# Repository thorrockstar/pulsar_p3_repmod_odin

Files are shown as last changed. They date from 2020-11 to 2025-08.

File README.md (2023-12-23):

Open Source Pulsar P3 Replacement Module 'Odin' & 'Loki'
========================================================

This project bundles my source code, binary, schematics and PCB layout files for my own Open Source Pulsar P3 LED watch replacement modules. I do **not** sell those modules or any component and I do **not** do any repairs. This project is purely for the enthusiast, that want to fix a Pulsar LED watch himself or herself, that is far beyond repair otherwise. This project is **not** meant to be used commercially.

The PCB layout is made in a way, allowing it to be opened and edited with the free Eagle version. I prefer the older Eagle 6.6 release, that still was made by CADSoft.

The free trial version of the CAD-Soft Eagle software can be found on CAD-Softs's own FTP server:
http://eagle.autodesk.com/eagle/software-versions/10

P3 Module Types
===============

This project contains two different boards. The **Odin Mark II** board, that can be used, if the **original Litronix** dotty LED display could be rescued. The **Loki** board can be used if the original display is broken and shall be replaced with four USSR made **AL304G replacement** single digit displays with common anodes. See the comments in the schematics.

**Note:** Some of the photos show **older** variants of the boards. So don't get confused. The current Odin Mark II features **4 extra transistors** for driving the common cathodes.

**Important Note:** As the new PCB's have traces and vias/pads on the back side, make sure you put some black isolation tape on top of the plastic carrier *before* placing the new PCB onto it. Otherwise the battery connection wires may short your PCB!

P4 Module Variant
=================

There is a sub-folder called 'p4mod', that contains a module called **Sif**. This one can be used for P4 Executive watches. It has the micro controller on the back side. So, double check the orientation of the chip, when soldering, as the PCB is shown from the top layer in the pictures and you need to turn the PCB over when soldering. Be aware, that you will need to **modify the plastic carrier**. You will be in need to make the open space behind the PCB wider, to be able to place the PCB flush on the P4 plastic carrier. I usually do that by cutting the edges on the top and bottom of the inner opening in order to create a 45 degree angle there.

License Agreement
=================

The software, source code, schematics, drawings and resources are provided to you by the Licensor under the License, as defined below, subject to the following condition.

Without limiting other conditions in the License, the grant of rights under the License will not include, and the License does not grant to you, the right to sell the software, source code, schematics, drawings or resources.

The Licensor does not grant the right to produce watch modules on the base of this work and then sell them as a product for profit.

These schematics, layout and source code files are free software; you can redistribute them and/or modify them under the terms of the GNU General Public License as published by the Free Software Foundation in version 2 of the License.

These source code, schematics, drawings and layout files are distributed in the hope that they will be useful, but WITHOUT ANY WARRANTY; without even the implied warranty of MERCHANTABILITY or FITNESS FOR A PARTICULAR PURPOSE. See the GNU General Public License for more details.

Hardware & Software
===================

This project features a MicroChip PIC18F24J11 MCU. The software can be compiled using Microchip's MPLAB IDE and the XC8 compiler. You can get those free for private use. To flash the controller I used a PICKIT™3 unit. You still get those units second hand or NOS but you can also use a more recent one.

**Module 'Odin' featuring the original display and light sensor.**

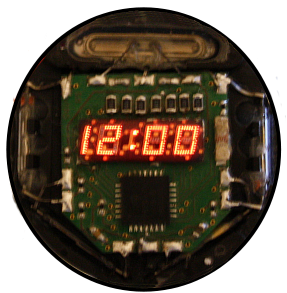
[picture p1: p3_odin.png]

(Older Odin 1)
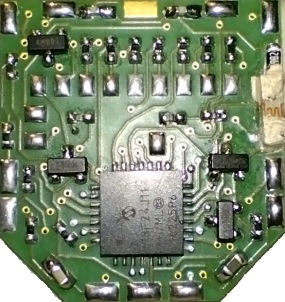
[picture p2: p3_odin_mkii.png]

(Newer Odin Mark II)

In the main header file, select the right type of watch module. You find also ready compiled binaries for the 'Odin' and 'Loki' module.

**Module 'Loki' featuring four replacement single digit displays and no light sensor.**

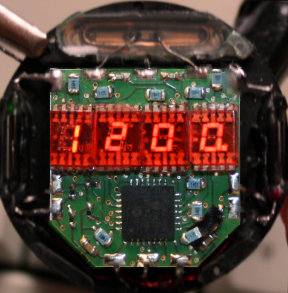
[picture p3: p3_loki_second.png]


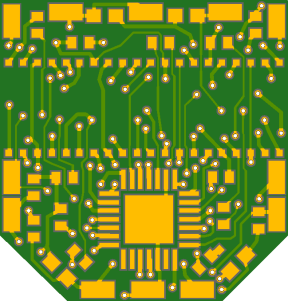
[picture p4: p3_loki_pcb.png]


Important
==========
We do **not** do any repairs or deliver any components. This is a pure Open Source project, were I share my files, that I used to create a replacement module for one of my old watches, that was corroded beyond repair. This project shall not be used commercially.

Contributing
============
To contribute to this project you should submit your proposals to the maintainer via GitHub.

Maintainer
==========
Dipl.-Ing.(FH) Roy Schneider

Useful Information
==================

More information about old Pulsar LED watches, can be found here:

Pulsar LED Watch Forum:
http://www.oldpulsars.com/

PCB
===

If you order your PCB at some manufacturer, go for the 1mm material thickness, not more. You need a thin PCB to ensure, you have enough clearance to the watch case glass, when the display has been installed. A traces thickness of 35 µm is good enough. Order the PCB with a solder stop mask. That simplifies soldering a lot. You usually do not need a silk screen. Order ENIG (Electroless Nickel Gold) surface (traces) for best solder results.

Energy Consumption
==================

The watch currently draws about 7 µA (0.007 mA) of current, if the display is not lit up. Assuming your silver oxide batteries would have 160mAh, the battery life time would be a year, depending how often you use the display. You may use Alkaline batteries but I suggest to use Silver Oxide batteries having 1.55V and a larger capacity.

Setting the Time & Date of the Replacement Module
=================================================

To forward the hours, place the magnet in the HOURS recess. To forward the minutes, place the magnet in the MINUTES recess. Keep in mind that the watch will stop counting the time, if you have forwarded the minutes, until you will press the first time the readout TIME button. This gives you an easy way to set the watch second-accurate, by setting the watch one minute into the future and then wait until the reference clock wraps to that very minute. If you press the TIME button in that moment, the watch will continue counting the time, having set the seconds to zero. To forward the month hold the DATE button pressed and place the magnet in the HOUR recess. To forward the day hold the DATE and TIME buttons pressed at the same time and place the magnet in the HOUR recess. This replacement module adds the weekday, the year and the light sensor read-out to the watch. Refer to the next chapter for setting them.

Settings the Extra Features of the Firmware not included in the original P3
===========================================================================

The firmware for this replacement module adds two additional functions to the watch. It adds the weekday and the year. To set the year hold the DATE and TIME button pressed and forward the year by putting the magnet into the MIN recess. To set the weekday hold only the DATE button pressed and forward the weekday by putting the magnet into the MIN recess. If you face the issue that you set the year instead of the weekday, then the magnet is very strong and engages not only the MIN but also the TIME reed contact. Try turning the magnet around in that case.

Optional Alarm Feature of the 'Loki Module'
============================================

This feature is only available for the 'Loki' modules, using the USSR made replacement displays. You can use the output RC2 of the micro controller in order to drive a disc piezo buzzer with a 820Ohm...1kOhm resistor in series. To use that feature turn the ALARM option on in the main.h header file and rebuild the binary.

**Note:**

Don't expect the alarm to be loud... it will not be loud enough to wake you up, simply because it is silenced by the massive metal case of the watch. :-)

**Set Alarm**

In order to set the alarm, press the TIME (hold) and then the DATE (hold) button in this exact order ands keep them pressed together. Now you can place the magnet in the HOUR or MIN recess to set the alarm.

**Toggle Alarm (on/off)**

To turn the alarm on or off press the TIME (hold) and then the DATE (hold) button in this exact order, then release the DATE button and press DATE again, while holding TIME still pressed, in order to toggle the alarm. A little dot on the right of the last AL304G display will indicate if the alarm is on or off.

Light Sensor Readout
====================

This applies only to the 'Odin' modules, if the light sensor option has been turned on. If you hold the DATE button pressed for more than a second, the watch will show the weekday and then, if you still keep the button pressed, the year. If you keep the button even longer pressed, a number will appear, that reflects the light sensor value. On normal daylight, that value shall be between two and four. On strong sun light five to six. If you are in dim light, the watch shall show one or zero. This readout is meant to make it easy to check, if the light sensor is working correctly.

Calibration
===========

The real-time crystal signal can be calibrated, so that the watch can provide an error of less than three seconds per month. If using the vintage original crystal, you will have easily 5 to 20 seconds drift per week, as those crystals are often hopelessly out tuned. By pressing the DATE button and holding it pressed, until the year or light sensor read out appears and then pressing the TIME button as well for a second, you will enter the drift calibration mode. You can now release the TIME button but keep the DATE pressed and use the magnet in the MIN recess to increase the calibration value. Use the HOUR recess to decrease the calibration value again. A positive value will speed up the watch by x\*0.6 seconds per week. A negative value will slow down the watch by x\*0.6 seconds by week. You can adjust the watch by a maximum ±38.76 seconds per week.

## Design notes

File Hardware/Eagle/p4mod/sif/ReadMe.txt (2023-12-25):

Hi!

This module can be used for P4 Executive watches. It has the micro controller on the back side.
So, double check the orientation of the chip as the PCB is shown from the top layer in the pictures but you have to flip around the PCB, when soldering the chip.

Be aware, that you will need to **modify the plastic carrier** for the **P4 version**.
You will be in need to make the open space wider to be able to place the PCB flush on the P4 plastic carrier. I usually do that by cutting the edges on the upper and lower side of the inner open space and create a 45 degree angle there. See the pictures.

In the header file of the main.h do not forget to set...

#define APP_WATCH_TYPE_BUILD    APP_PULSAR_P4_WRIST_WATCH_12H_SIF_MARK_II_MOD

...when building for the P4 SiF module! You can also use the pre-compiled binary called "pulsar_p4_sif_litronix_firmware.hex" for flashing the micro controller instead.

Kind regards

Roy

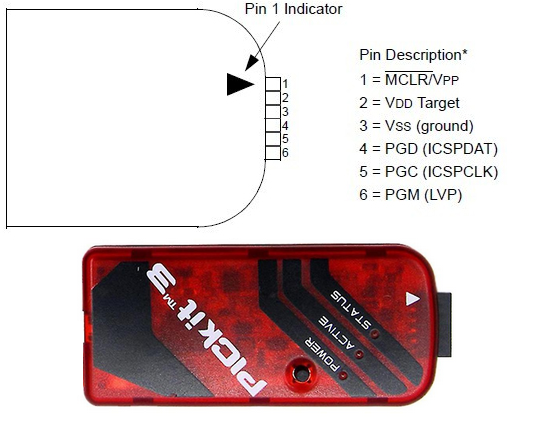
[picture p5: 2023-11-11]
PickIt3_Pinout.png

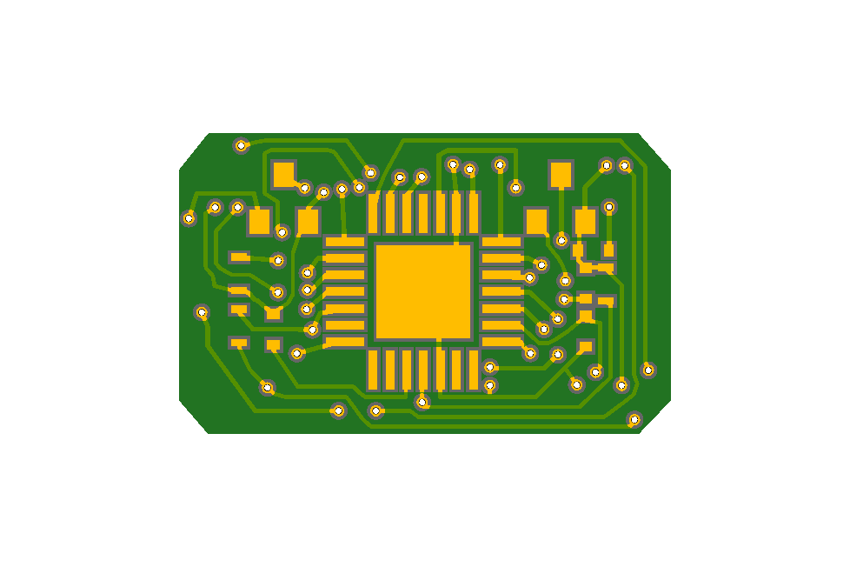
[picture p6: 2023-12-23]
Hardware/Eagle/p4mod/sif/sif_mod_bottom.png

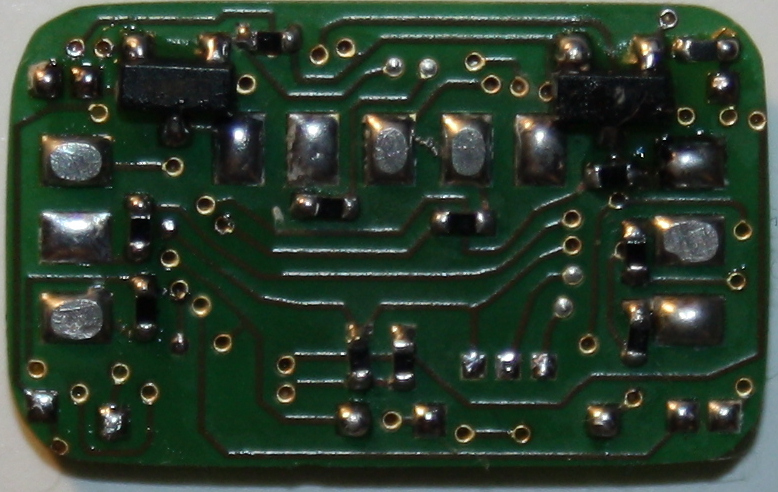
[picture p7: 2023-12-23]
Hardware/Eagle/p4mod/sif/sif_mkII_2.jpg

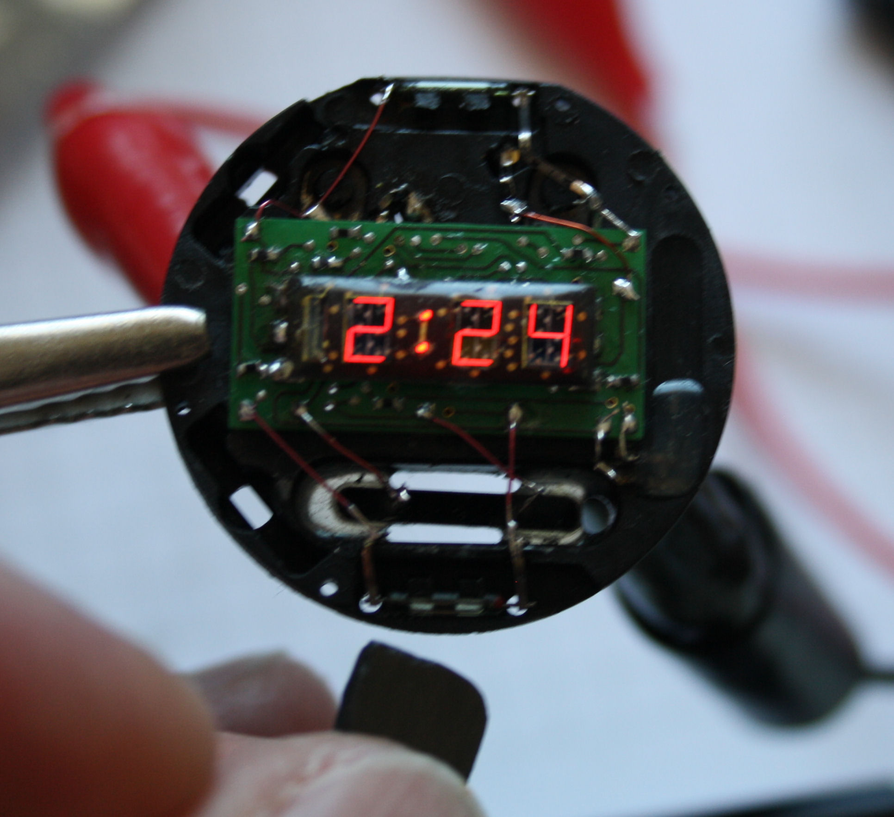
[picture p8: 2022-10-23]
Hardware/Eagle/p4mod/sif/sif5.jpg

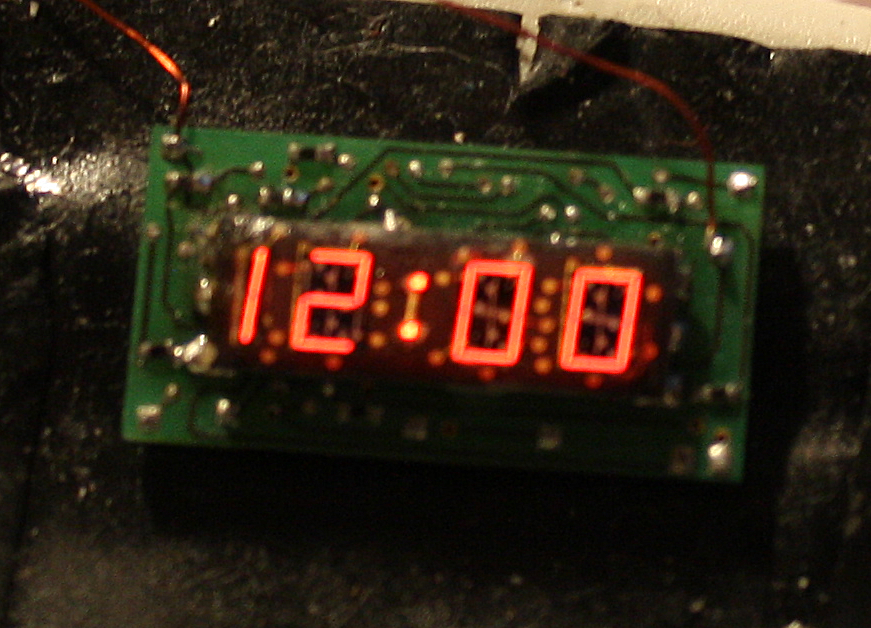
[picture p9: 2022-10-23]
Hardware/Eagle/p4mod/sif/sif.png

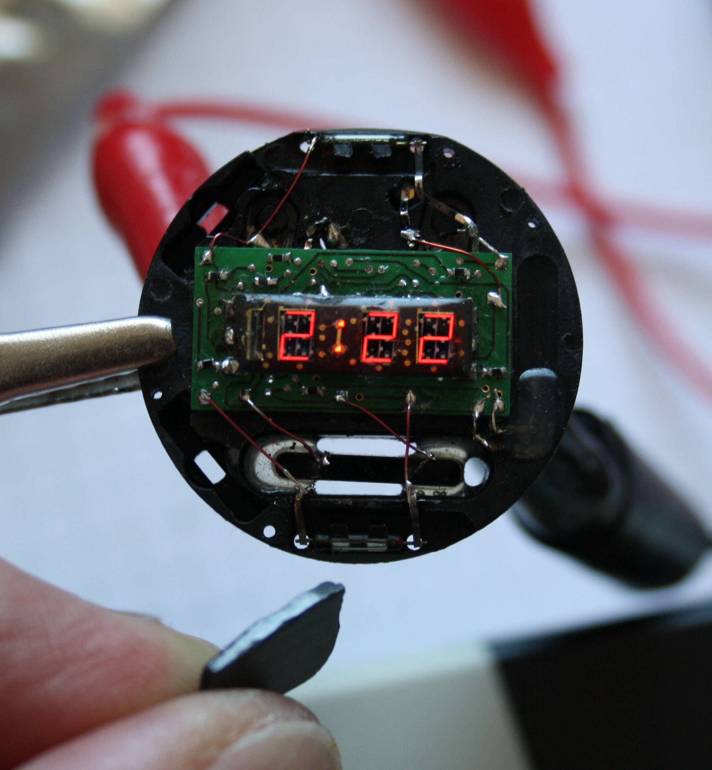
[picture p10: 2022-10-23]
Hardware/Eagle/p4mod/sif/sif2.jpg

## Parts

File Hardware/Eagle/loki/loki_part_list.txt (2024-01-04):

Partlist Loki Pulsar P3 replacement module with replacement displays

4x Displays AL304G (common anode)
1x BUZZER   Piezo disc 18 mm (about 200 Ohm)

CEFC     10 uF             C0603
C2       100 nF            CO603

C4       12 pF             CO603 or C0402
C5       12 pF             CO603 or C0402

R1       10K               R0402
R10      470               R0402

R14      4.7k              R0402
R15      4.7k              R0402
R16      4.7k              R0402
R17      4.7k              R0402

R2       130               R0402
R3       130               R0402
R4       130               R0402
R5       130               R0402
R6       130               R0402
R7       130               R0402
R8       130               R0402
R9       130               R0402

MCU      PIC18F24J11-I/ML QFN

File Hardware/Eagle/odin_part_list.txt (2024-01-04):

Partlist Odin Mark II Pulsar P3 replacement module

C4       12 pF             C0603 or C0402
C5       12 pF             C0603 or C0402

CEFC     10 uF             C0603
C2       100 nF            C0603

Q1       IRLML0030         SOT-23
Q2       IRLML0030         SOT-23
Q3       IRLML0030         SOT-23
Q4       IRLML0030         SOT-23

R1       10K               R0402

R9       47k               R0402
R10      47k               R0402
R11      47k               R0402
R12      47k               R0402
R13      47k               R0402

R14      4.7k              R0402
R15      4.7k              R0402
R16      4.7k              R0402
R17      4.7k              R0402

R2       82                R0402
R3       82                R0402
R4       82                R0402
R5       82                R0402
R6       82                R0402
R7       82                R0402
R8       82                R0402

MCU      PIC18F24J11-I/ML QFN

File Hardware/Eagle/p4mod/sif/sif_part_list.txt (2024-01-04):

Partlist Sif Mark II Pulsar P4 replacement module

C1       12 pF             C0402
C4       12 pF             C0402
C2       100 nF            C0402

CEFC     10 uF             C0603

Q1       IRLML0030         SOT-23
Q2       IRLML0030         SOT-23
Q3       IRLML0030         SOT-23
Q4       IRLML0030         SOT-23

R1       10K               R0402

R9       47k               R0402
R10      47k               R0402
R11      47k               R0402
R12      47k               R0402

R16      4.7k              R0402
R17      4.7k              R0402

R2       82                R0402
R3       82                R0402
R4       82                R0402
R5       82                R0402
R6       82                R0402
R7       82                R0402
R8       82                R0402

MCU      PIC18F24J11-I/ML QFN

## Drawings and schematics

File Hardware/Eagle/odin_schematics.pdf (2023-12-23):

1 47k

# TRIM R⁹

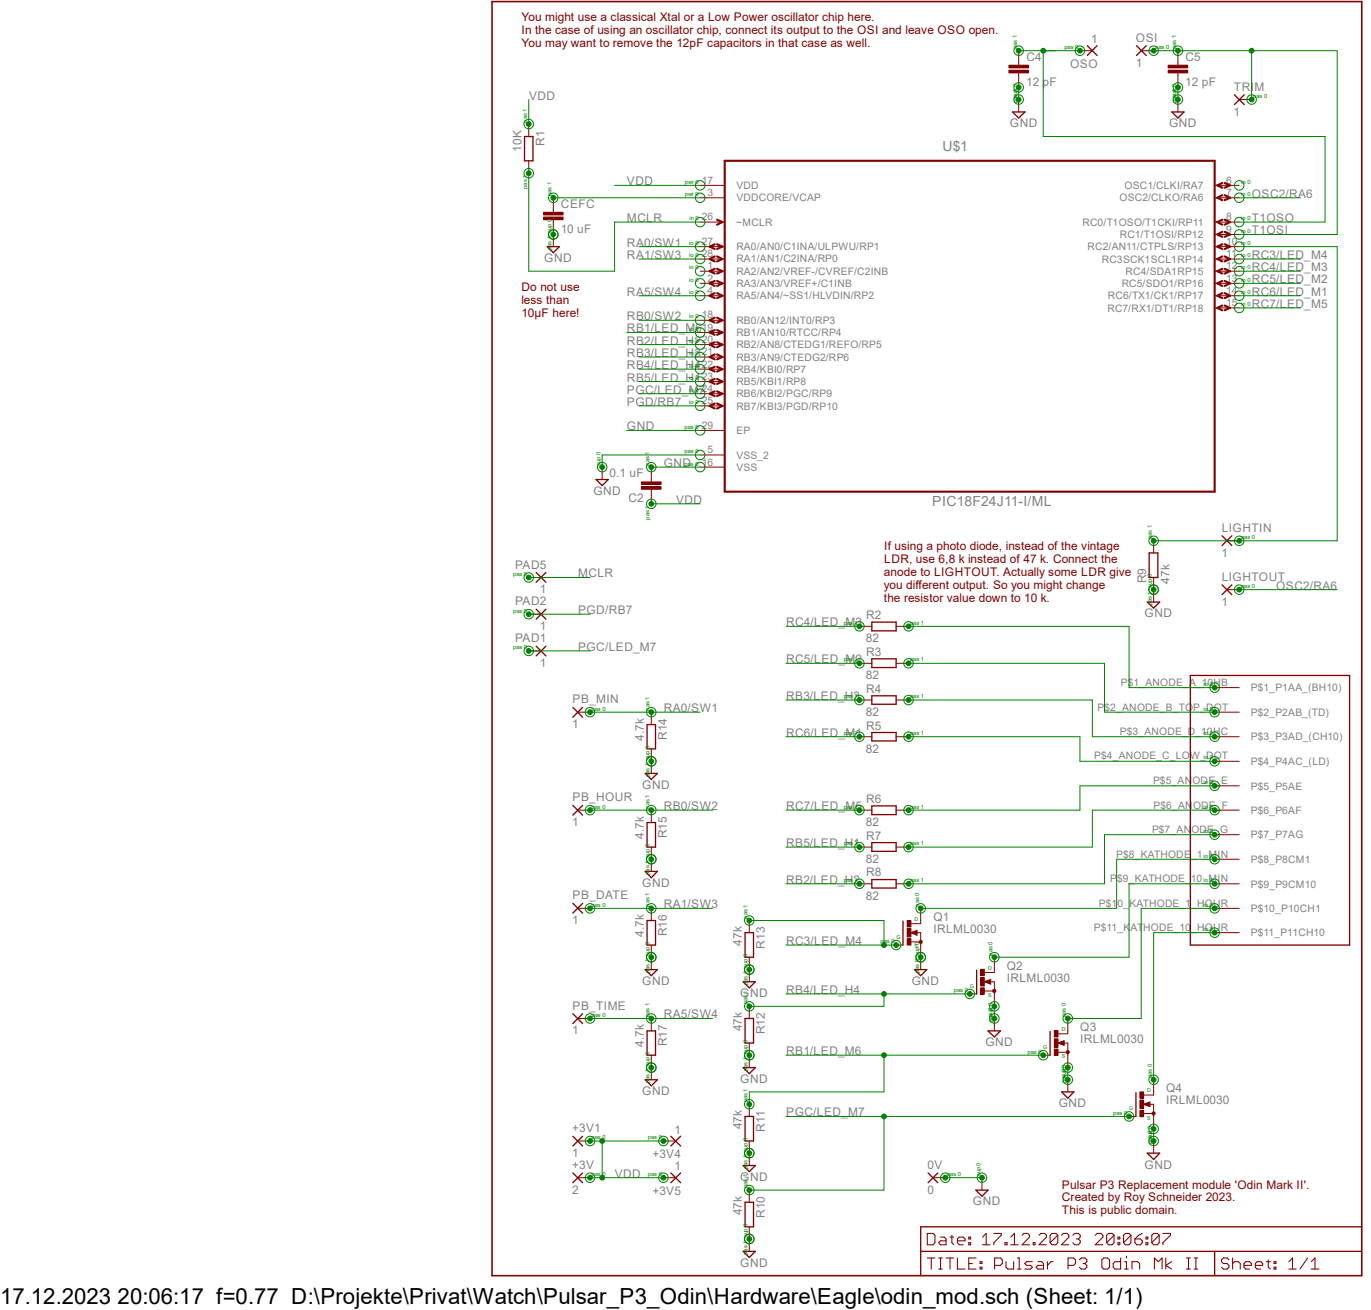
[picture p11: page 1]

You might use a classical Xtal or a Low Power oscillator chip here.
In the case of using an oscillator chip, connect its output to the OSI and leave OSO open.

You may want to remove the 12pF capacitors in that case as well.

If using a photo diode, instead of the vintage
LDR, use 6,8 k instead of 47 k. Connect the
anode to LIGHTOUT. Actually some LDR give
you different output. So you might change
the resistor value down to 10 k.

GND 47k 47k 47k 47k GND
Q4 R¹⁰ R¹¹ R¹² R¹³
RC3/LED_M4

Pulsar P3 Replacement module 'Odin Mark II'.
Created by Roy Schneider 2023.
This is public domain.

17.12.2023 20:06:17 f=0.77 D:\Projekte\Privat\Watch\Pulsar_P3_Odin\Hardware\Eagle\odin_mod.sch (Sheet: 1/1)

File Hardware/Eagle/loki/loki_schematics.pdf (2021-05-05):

pas 1 | pas 1 pas 1 pas 1 pas 1 pas 1 | sup 0 sup 0 sup 0 | pas 1 pas 1 | pas 1 pas 1 sup 0 | sup 0
pas 0 io 0 | io 0 | io 0 | io 0 | io 0 io 0 | io 0 | io 0 | io 0 | io 0 io 0 | io 0 | io 0 | io 0 | io 0 io 0 | io 0 | io 0 | io 0 | io 0 io 0 | io 0 | io 0 | io 0 | io 0 io 0 | io 0 | io 0 | io 0 | io 0 io 0 | io 0 | io 0 | io 0 | io 0 io 0 | io 0 | io 0 | io 0 | io 0 | pas 1 pas 1

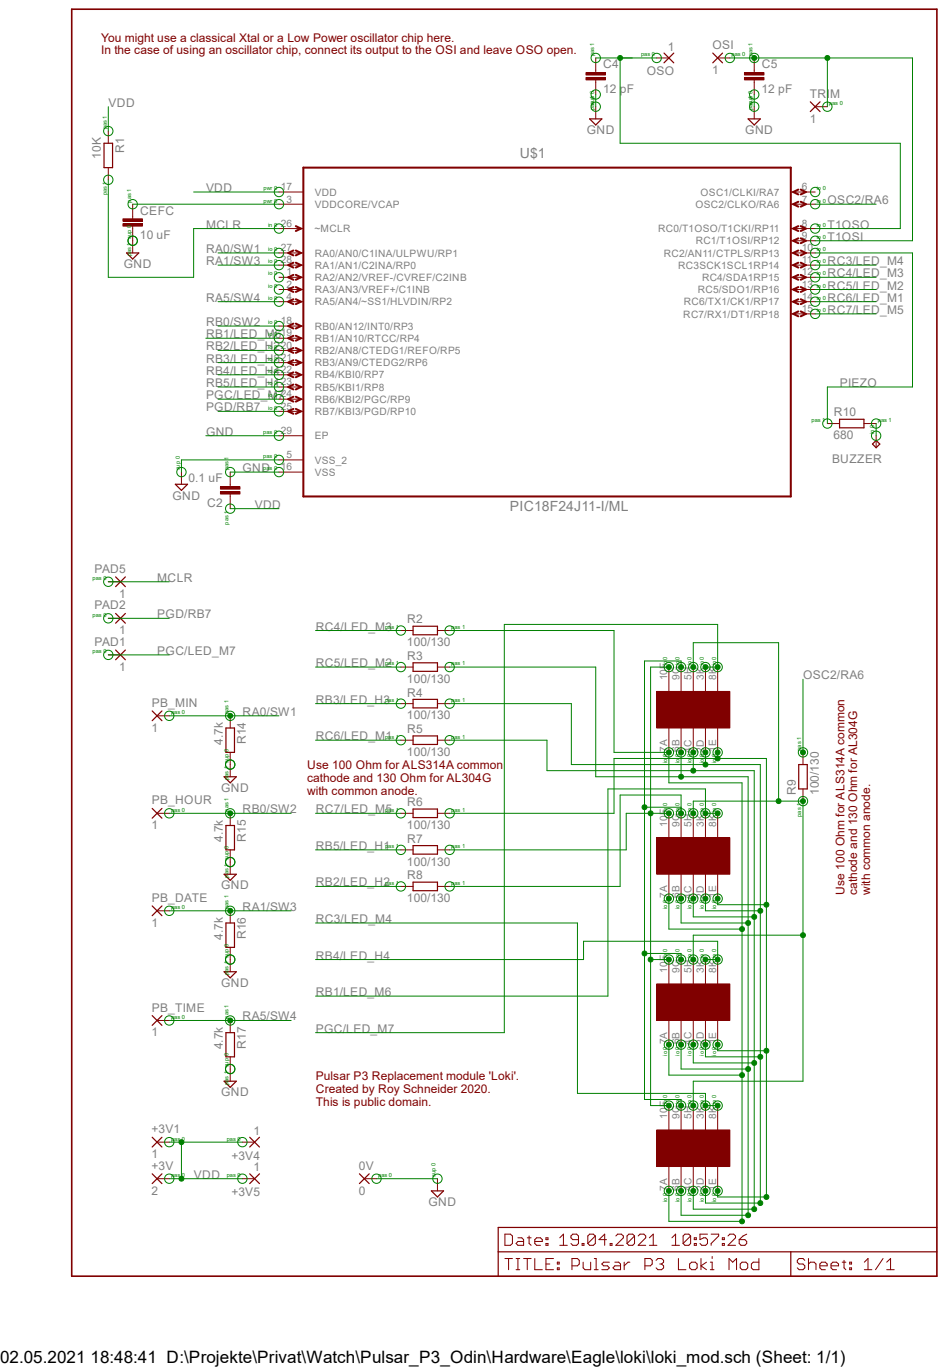
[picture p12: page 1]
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

Use 100 Ohm for ALS314A common
cathode and 130 Ohm for AL304G

Pulsar P3 Replacement module 'Loki'.
Created by Roy Schneider 2020.
This is public domain.

02.05.2021 18:48:41 D:\Projekte\Privat\Watch\Pulsar_P3_Odin\Hardware\Eagle\loki\loki_mod.sch (Sheet: 1/1)

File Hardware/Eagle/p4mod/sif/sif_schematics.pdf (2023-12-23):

## PIC18F24J11-I/ML ¹⁰K

# GND 47k

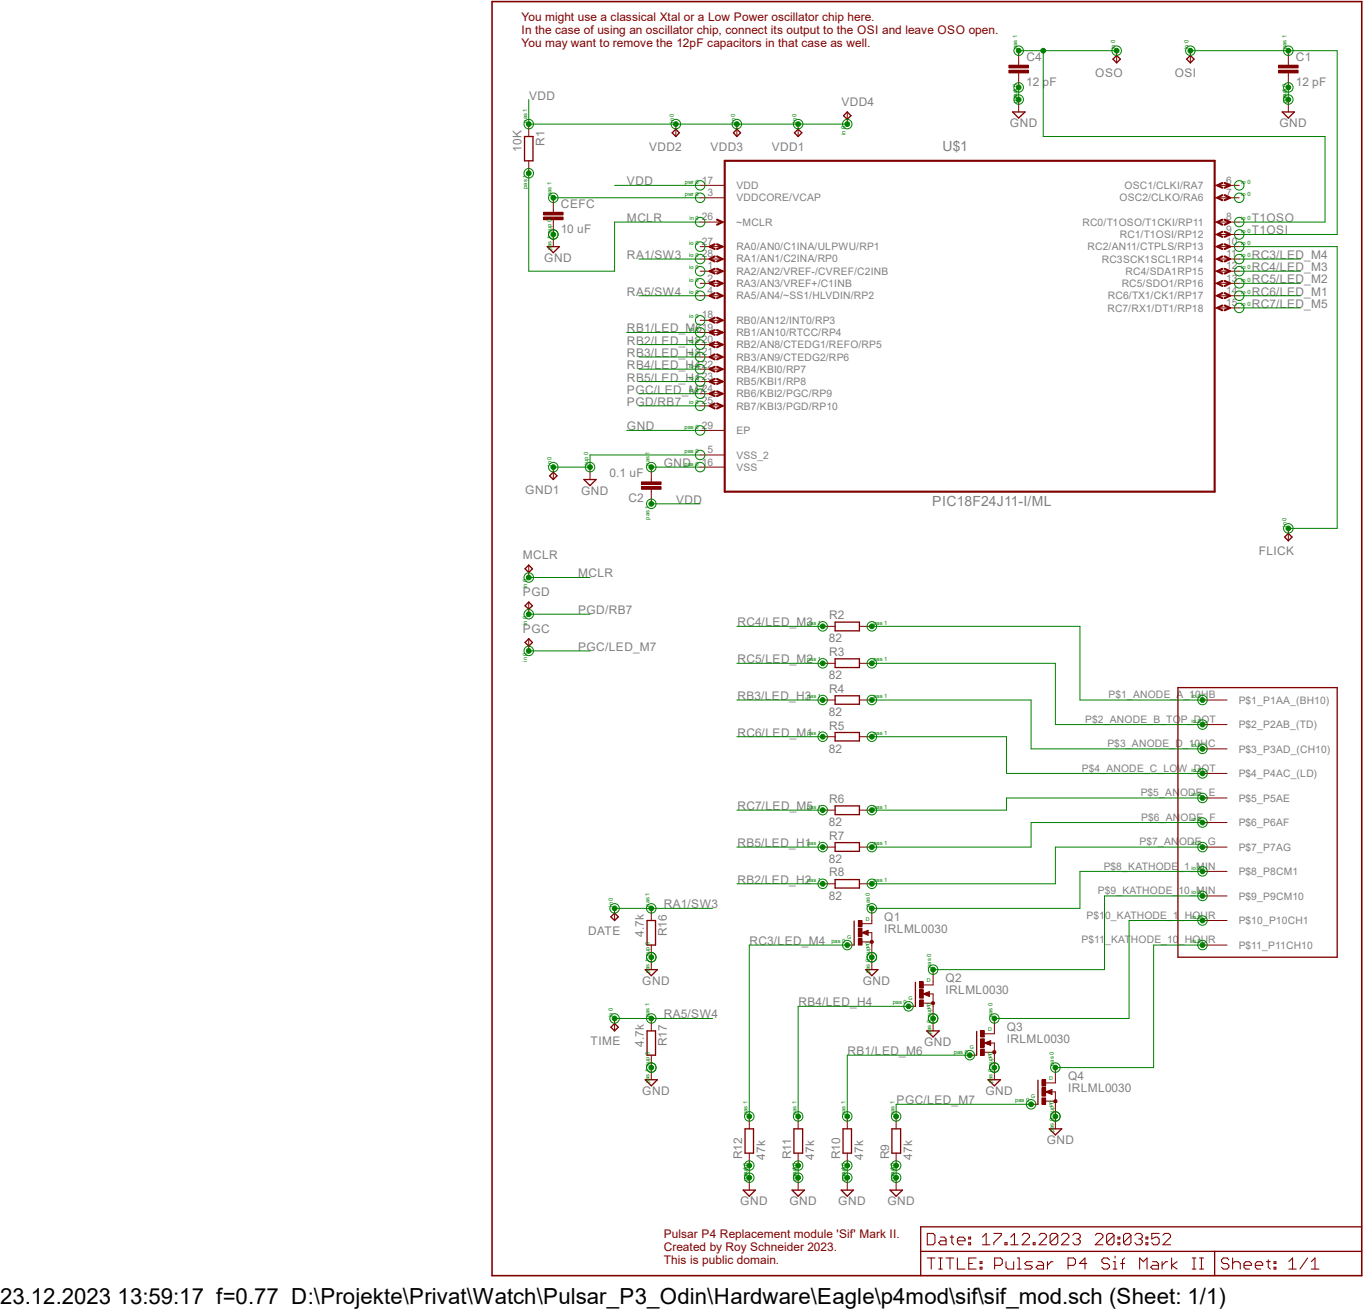
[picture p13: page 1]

You might use a classical Xtal or a Low Power oscillator chip here.
In the case of using an oscillator chip, connect its output to the OSI and leave OSO open.
You may want to remove the 12pF capacitors in that case as well.
C4 R¹⁶ R¹⁷

Pulsar P4 Replacement module 'Sif' Mark II.
Created by Roy Schneider 2023.
This is public domain.

23.12.2023 13:59:17 f=0.77 D:\Projekte\Privat\Watch\Pulsar_P3_Odin\Hardware\Eagle\p4mod\sif\sif_mod.sch (Sheet: 1/1)

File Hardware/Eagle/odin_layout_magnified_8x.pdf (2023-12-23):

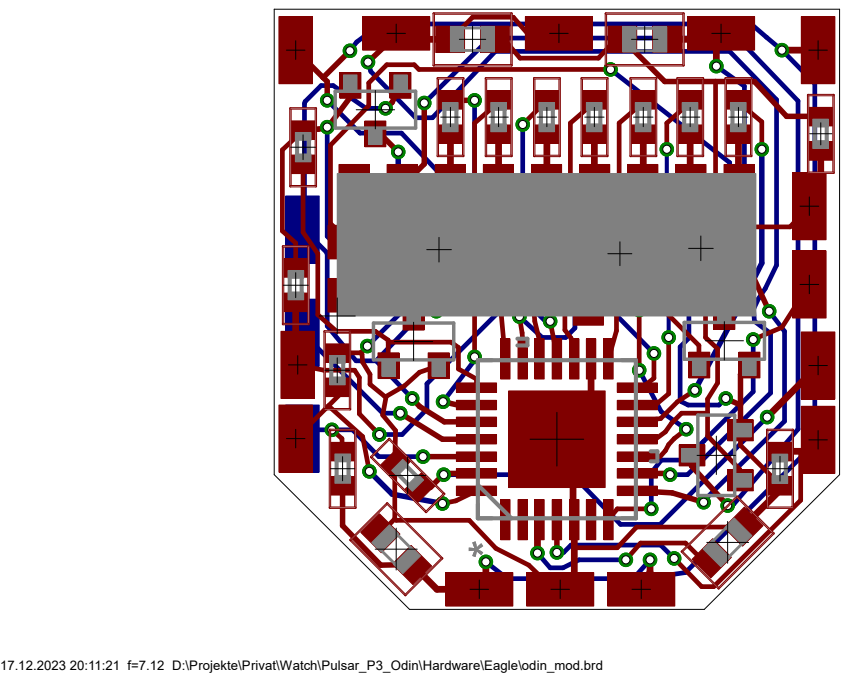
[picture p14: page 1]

17.12.2023 20:11:21 f=7.12 D:\Projekte\Privat\Watch\Pulsar_P3_Odin\Hardware\Eagle\odin_mod.brd

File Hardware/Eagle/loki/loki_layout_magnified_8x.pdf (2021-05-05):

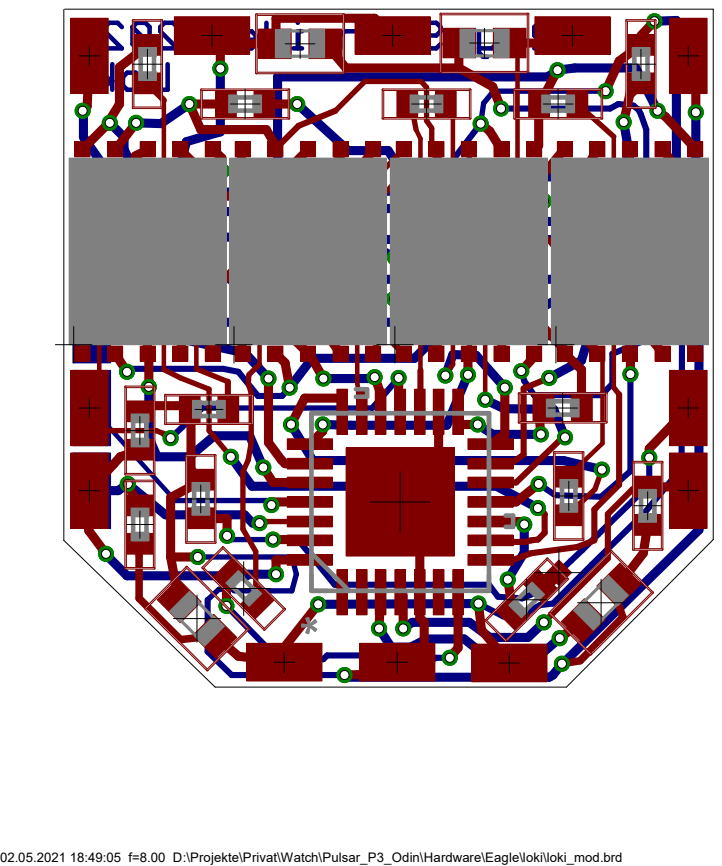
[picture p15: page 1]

02.05.2021 18:49:05 f=8.00 D:\Projekte\Privat\Watch\Pulsar_P3_Odin\Hardware\Eagle\loki\loki_mod.brd

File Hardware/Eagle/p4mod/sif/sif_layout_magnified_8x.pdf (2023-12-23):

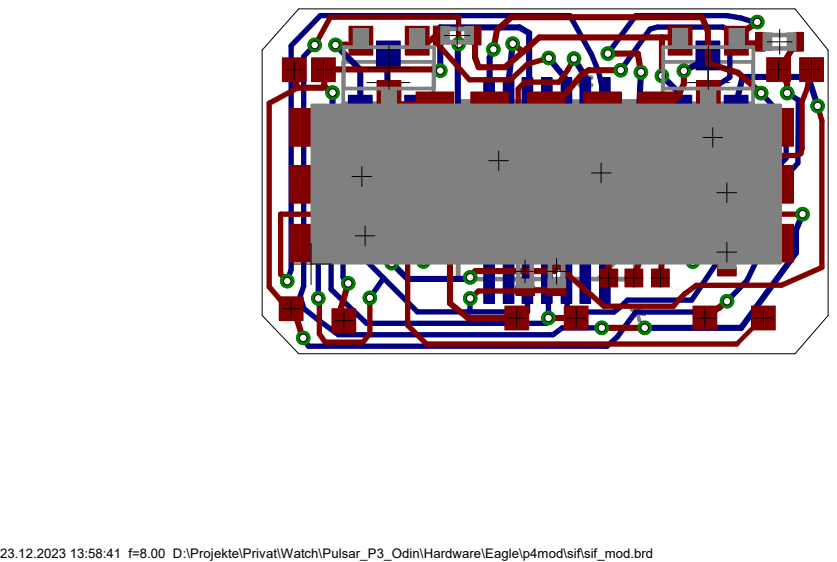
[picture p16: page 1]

23.12.2023 13:58:41 f=8.00 D:\Projekte\Privat\Watch\Pulsar_P3_Odin\Hardware\Eagle\p4mod\sif\sif_mod.brd

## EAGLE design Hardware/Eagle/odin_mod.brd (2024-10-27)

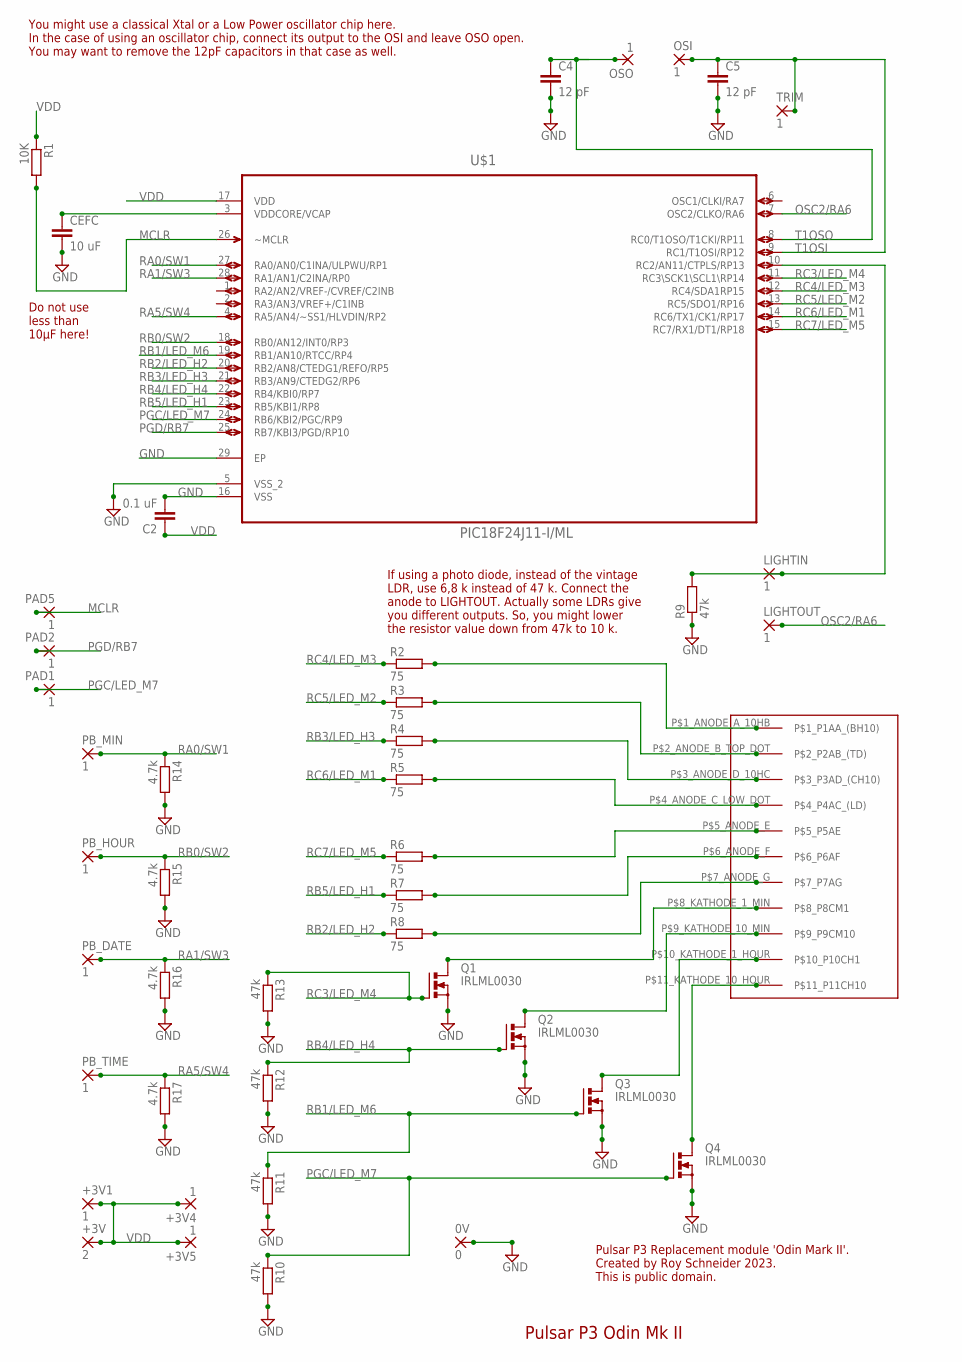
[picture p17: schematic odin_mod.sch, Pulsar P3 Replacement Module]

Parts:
0V: 0; SMD1,27-2,54
+3V: 2; SMD1,27-2,54
+3V1, +3V4, +3V5: 1; SMD1,27-2,54
C2: 0.1 uF; C0603
C4, C5: 12 pF; C0603
CEFC: 10 uF; C0603
LIGHTIN: 1; SMD1,27-2,54
LIGHTOUT: 1; SMD1,27-2,54
OSI: 1; SMD1,27-2,54
OSO: 1; SMD1,27-2,54
PAD1, PAD2, PAD5: 1; SMD1,27-2,54
PB_DATE: 1; SMD1,27-2,54
PB_HOUR: 1; SMD1,27-2,54
PB_MIN: 1; SMD1,27-2,54
PB_TIME: 1; SMD1,27-2,54
Q1, Q2, Q3, Q4: IRLML0030; SOT-23
R1: 10K; R0402
R2, R3, R4, R5, R6, R7, R8: 75; R0402
R9, R10, R11, R12, R13: 47k; R0402
R14, R15, R16, R17: 4.7k; R0402
TRIM: 1; SMD1,27-2,54
U$1: PIC18F24J11-I/ML; QFN65P600X600X100-29N
U$3: PULSAR_P3_DISPLAY; PULSAR_P3_LED_DISPLAY

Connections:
GND: 0V.1, C2.2, C4.2, C5.2, CEFC.2, Q1.P2 (S), Q2.P2 (S), Q3.P2 (S), Q4.P2 (S), R9.1, R10.2, R11.2, R12.2, R13.2, R14.2, R15.2, R16.2, R17.2, U$1.5 (VSS_2), U$1.16 (VSS), U$1.29 (EP)
MCLR: PAD5.1, R1.2, U$1.26 (~MCLR)
unnamed: LIGHTIN.1, R9.2, U$1.10 (RC2/AN11/CTPLS/RP13)
unnamed: R2.2, U$3.P$1_ANODE_A_10HB (P$1_P1AA_(BH10))
unnamed: R3.2, U$3.P$2_ANODE_B_TOP_DOT (P$2_P2AB_(TD))
unnamed: R4.2, U$3.P$3_ANODE_D_10HC (P$3_P3AD_(CH10))
unnamed: R5.2, U$3.P$4_ANODE_C_LOW_DOT (P$4_P4AC_(LD))
unnamed: R6.2, U$3.P$5_ANODE_E (P$5_P5AE)
unnamed: R7.2, U$3.P$6_ANODE_F (P$6_P6AF)
unnamed: R8.2, U$3.P$7_ANODE_G (P$7_P7AG)
unnamed: Q4.P3 (D), U$3.P$11_KATHODE_10_HOUR (P$11_P11CH10)
unnamed: Q3.P3 (D), U$3.P$10_KATHODE_1_HOUR (P$10_P10CH1)
unnamed: Q2.P3 (D), U$3.P$9_KATHODE_10_MIN (P$9_P9CM10)
unnamed: Q1.P3 (D), U$3.P$8_KATHODE_1_MIN (P$8_P8CM1)
OSC2/RA6: LIGHTOUT.1, U$1.7 (OSC2/CLKO/RA6)
PGC/LED_M7: PAD1.1, Q4.P1 (G), R10.1, U$1.24 (RB6/KBI2/PGC/RP9)
PGD/RB7: PAD2.1, U$1.25 (RB7/KBI3/PGD/RP10)
RA0/SW1: PB_MIN.1, R14.1, U$1.27 (RA0/AN0/C1INA/ULPWU/RP1)
RA1/SW3: PB_DATE.1, R16.1, U$1.28 (RA1/AN1/C2INA/RP0)
RA5/SW4: PB_TIME.1, R17.1, U$1.4 (RA5/AN4/~SS1/HLVDIN/RP2)
RB0/SW2: PB_HOUR.1, R15.1, U$1.18 (RB0/AN12/INT0/RP3)
RB1/LED_M6: Q3.P1 (G), R11.1, U$1.19 (RB1/AN10/RTCC/RP4)
RB2/LED_H2: R8.1, U$1.20 (RB2/AN8/CTEDG1/REFO/RP5)
RB3/LED_H3: R4.1, U$1.21 (RB3/AN9/CTEDG2/RP6)
RB4/LED_H4: Q2.P1 (G), R12.1, U$1.22 (RB4/KBI0/RP7)
RB5/LED_H1: R7.1, U$1.23 (RB5/KBI1/RP8)
RC3/LED_M4: Q1.P1 (G), R13.1, U$1.11 (RC3\SCK1\SCL1\RP14)
RC4/LED_M3: R2.1, U$1.12 (RC4/SDA1RP15)
RC5/LED_M2: R3.1, U$1.13 (RC5/SDO1/RP16)
RC6/LED_M1: R5.1, U$1.14 (RC6/TX1/CK1/RP17)
RC7/LED_M5: R6.1, U$1.15 (RC7/RX1/DT1/RP18)
T1OSI: C5.1, OSI.1, TRIM.1, U$1.9 (RC1/T1OSI/RP12)
T1OSO: C4.1, OSO.1, U$1.8 (RC0/T1OSO/T1CKI/RP11)
VDD: +3V.1, +3V1.1, +3V4.1, +3V5.1, C2.1, R1.1, U$1.17 (VDD)
VDDCORE/VCAP: CEFC.1, U$1.3 (VDDCORE/VCAP)

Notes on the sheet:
You might use a classical Xtal or a Low Power oscillator chip here. In the case of using an oscillator chip, connect its output to the OSI and leave OSO open. You may want to remove the 12pF capacitors in that case as well.
Pulsar P3 Replacement module 'Odin Mark II'. Created by Roy Schneider 2023. This is public domain.
Pulsar P3 Odin Mk II
If using a photo diode, instead of the vintage LDR, use 6,8 k instead of 47 k. Connect the anode to LIGHTOUT. Actually some LDRs give you different outputs. So, you might lower the resistor value down from 47k to 10 k.
Do not use less than 10µF here!

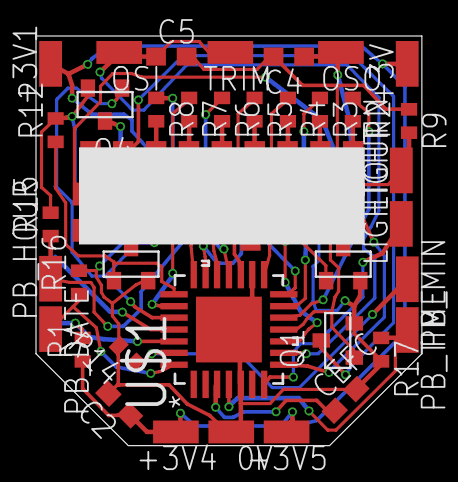
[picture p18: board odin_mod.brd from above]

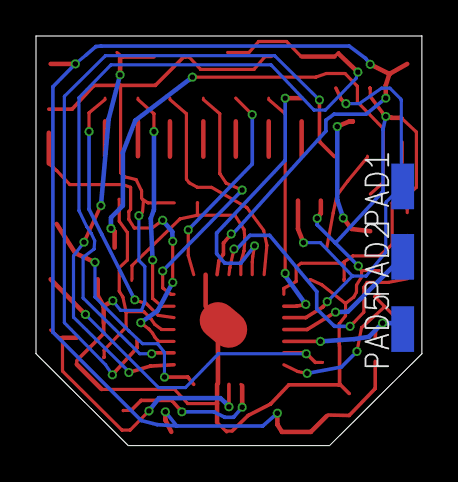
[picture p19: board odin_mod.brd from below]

Board: 2 copper layers, 21.4 x 22.8 mm, 44 parts (3 on the bottom side), 35 nets.

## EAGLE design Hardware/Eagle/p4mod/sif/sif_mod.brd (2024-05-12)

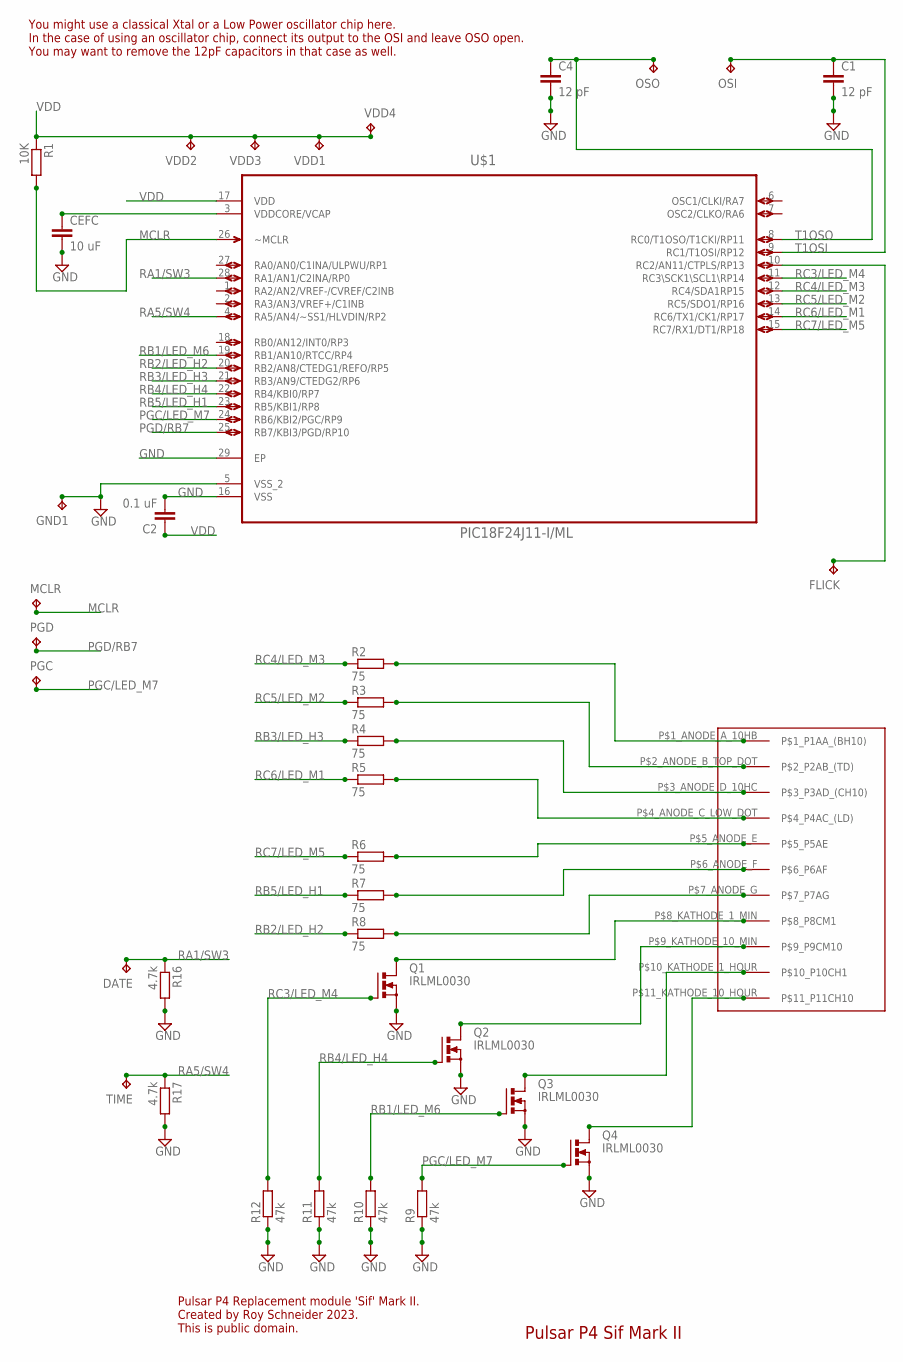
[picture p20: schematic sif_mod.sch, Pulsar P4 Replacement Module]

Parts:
C1, C4: 12 pF; C0402K
C2: 0.1 uF; C0402K
CEFC: 10 uF; C0603
DATE: TPTP08SQ; TP08SQ
FLICK: TPTP08SQ; TP08SQ
GND1: TPTP08SQ; TP08SQ
MCLR: TPTP06SQ; TP06SQ
OSI: TPTP08SQ; TP08SQ
OSO: TPTP08SQ; TP08SQ
PGC: TPTP06SQ; TP06SQ
PGD: TPTP06SQ; TP06SQ
Q1, Q2, Q3, Q4: IRLML0030; SOT-23
R1: 10K; R0402
R2, R3, R4, R5, R6, R7, R8: 75; R0402
R9, R10, R11, R12: 47k; R0402
R16, R17: 4.7k; R0402
TIME: TPTP08SQ; TP08SQ
U$1: PIC18F24J11-I/ML; QFN65P600X600X100-29N
U$2: PULSAR_P4_DISPLAYPULSAR_P4_LED_DISPLAY; PULSAR_P3_LED_DISPLAY
VDD1, VDD2, VDD3, VDD4: TPTP08SQ; TP08SQ

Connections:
GND: C1.2, C2.2, C4.2, CEFC.2, GND1.TP, Q1.P2 (S), Q2.P2 (S), Q3.P2 (S), Q4.P2 (S), R9.1, R10.1, R11.1, R12.1, R16.2, R17.2, U$1.5 (VSS_2), U$1.16 (VSS), U$1.29 (EP)
MCLR: MCLR.TP, R1.2, U$1.26 (~MCLR)
unnamed: FLICK.TP, U$1.10 (RC2/AN11/CTPLS/RP13)
unnamed: R8.2, U$2.P$7_ANODE_G (P$7_P7AG)
unnamed: R7.2, U$2.P$6_ANODE_F (P$6_P6AF)
unnamed: R6.2, U$2.P$5_ANODE_E (P$5_P5AE)
unnamed: R5.2, U$2.P$4_ANODE_C_LOW_DOT (P$4_P4AC_(LD))
unnamed: R4.2, U$2.P$3_ANODE_D_10HC (P$3_P3AD_(CH10))
unnamed: R3.2, U$2.P$2_ANODE_B_TOP_DOT (P$2_P2AB_(TD))
unnamed: R2.2, U$2.P$1_ANODE_A_10HB (P$1_P1AA_(BH10))
unnamed: Q2.P3 (D), U$2.P$9_KATHODE_10_MIN (P$9_P9CM10)
unnamed: Q3.P3 (D), U$2.P$10_KATHODE_1_HOUR (P$10_P10CH1)
unnamed: Q4.P3 (D), U$2.P$11_KATHODE_10_HOUR (P$11_P11CH10)
unnamed: Q1.P3 (D), U$2.P$8_KATHODE_1_MIN (P$8_P8CM1)
PGC/LED_M7: PGC.TP, Q4.P1 (G), R9.2, U$1.24 (RB6/KBI2/PGC/RP9)
PGD/RB7: PGD.TP, U$1.25 (RB7/KBI3/PGD/RP10)
RA1/SW3: DATE.TP, R16.1, U$1.28 (RA1/AN1/C2INA/RP0)
RA5/SW4: R17.1, TIME.TP, U$1.4 (RA5/AN4/~SS1/HLVDIN/RP2)
RB1/LED_M6: Q3.P1 (G), R10.2, U$1.19 (RB1/AN10/RTCC/RP4)
RB2/LED_H2: R8.1, U$1.20 (RB2/AN8/CTEDG1/REFO/RP5)
RB3/LED_H3: R4.1, U$1.21 (RB3/AN9/CTEDG2/RP6)
RB4/LED_H4: Q2.P1 (G), R11.2, U$1.22 (RB4/KBI0/RP7)
RB5/LED_H1: R7.1, U$1.23 (RB5/KBI1/RP8)
RC3/LED_M4: Q1.P1 (G), R12.2, U$1.11 (RC3\SCK1\SCL1\RP14)
RC4/LED_M3: R2.1, U$1.12 (RC4/SDA1RP15)
RC5/LED_M2: R3.1, U$1.13 (RC5/SDO1/RP16)
RC6/LED_M1: R5.1, U$1.14 (RC6/TX1/CK1/RP17)
RC7/LED_M5: R6.1, U$1.15 (RC7/RX1/DT1/RP18)
T1OSI: C1.1, OSI.TP, U$1.9 (RC1/T1OSI/RP12)
T1OSO: C4.1, OSO.TP, U$1.8 (RC0/T1OSO/T1CKI/RP11)
VDD: C2.1, R1.1, U$1.17 (VDD), VDD1.TP, VDD2.TP, VDD3.TP, VDD4.TP
VDDCORE/VCAP: CEFC.1, U$1.3 (VDDCORE/VCAP)

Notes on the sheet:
You might use a classical Xtal or a Low Power oscillator chip here. In the case of using an oscillator chip, connect its output to the OSI and leave OSO open. You may want to remove the 12pF capacitors in that case as well.
Pulsar P4 Replacement module 'Sif' Mark II. Created by Roy Schneider 2023. This is public domain.
Pulsar P4 Sif Mark II

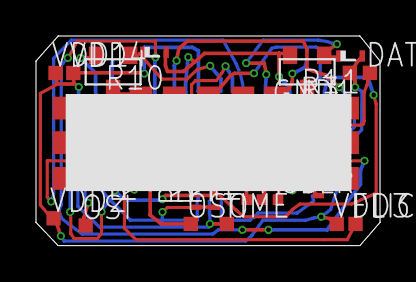
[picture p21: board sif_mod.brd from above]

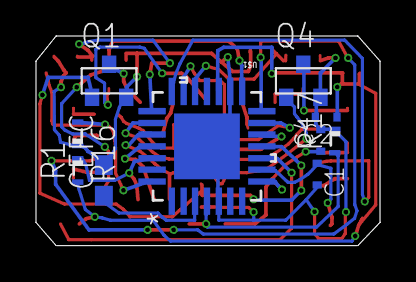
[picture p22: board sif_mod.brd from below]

Board: 2 copper layers, 19.1 x 11.6 mm, 37 parts (10 on the bottom side), 32 nets.

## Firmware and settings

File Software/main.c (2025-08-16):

/**
 *  Copyright (c) 2020-25 Roy Schneider
 *
 *  main.c
 *
 *  Implementation of the Pulsar P3/P4 internal watch logic.
 *
 *  Project:            Pulsar P3 (3013/50) Replacement modules 'Odin' & 'Loki'.
 *                      Pulsar P4 (403) Replacement modules 'Sif' & 'Hel'.
 *                      Pulsar P4 (401) Replacement modules 'Sif' for Ladies.
 *                      The 'Odin' & 'Sif' modules are featuring the original
 *                      Litronix made (dotty) display, while the 'Loki' & 'Hel'
 *                      modules are featuring an USSR made AL304G display.
 *                      The 'Loki' and 'Hel' modules are used in the case the
 *                      original display is corroded beyond repair.
 *
 *  Programmer:         Roy Schneider
 *  Last Change:        16.08.2025
 *
 *  Language:           C
 *  Toolchain:          GCC/GNU-Make
 *
 * Software License Agreement
 *
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
 * As a special exception, if other files instantiate templates or
 * use macros or inline functions from this file, or you compile
 * this file and link it with other works to produce a work based
 * on this file, this file does not by itself cause the resulting
 * work to be covered by the GNU General Public License. However
 * the source code for this file must still be made available in
 * accordance with section (3) of the GNU General Public License.
 *
 * This exception does not invalidate any other reasons why a work
 * based on this file might be covered by the GNU General Public
 * License.
 *
 * Input and Output Assignment
 *
 * Reed switches:
 * RA5 - Time readout button on the right/lower side of the watch.
 * RA1 - Date readout button on the left/upper side of the watch.
 * RB0 - Hour set button (Magnet set)
 * RA0 - Minute set button (Magnet set)
 * RC2 - Wrist flick, which can not be used together with the light sensor
 *       or the buzzer support. The wrist flick feature is only supported for
 *       watches, featuring Auto-Set and not for those that feature Magnet-Set.
 *
 * Segments:
 * There is a macro in the header file, that let you select these outputs
 * to be anodes or cathodes.
 * RC4 'A' (but 'B' for the left most 10h digit of the Litronix display)
 * RC5 'B' (but 'top dot' in the middle of the Litronix display)
 * RC6 'C' (but 'lower dot' in the middle of the Litronix display)
 * RC7 'E'
 * RB2 'G'
 * RB3 'D' (but 'C' for the left most 10h digit of the Litronix display)
 * RB5 'F'
 * RA6 for the date and alarm dots of the replacement ALS314A or AL304G display.
 *
 * Common:
 * There is a macro in the header file, that let you select these outputs
 * to be anodes or cathodes.
 * RC3 for '1' minute
 * RB4 for '10' minute
 * RB1 for '1' hour
 * RB6 for '10' hour and the dots of the 12h Litronix display
 *
 * Light sensor option
 * RA6 provides power to the light sensor, when measuring
 * RC2 used as AN11 analogue input to measure the light indirectly
 *
 * Optional buzzer option (mutual exlude with the light sensor option)
 * RA6 used for the alarm dot
 * RC2 used as PWM to drive the piezo
 * 
 * RC0 RTCC Xtal OSO
 * RC1 RTCC Xtal OSI
 */

/* Include the right header file for the PIC microcontroller used. */

#include <p18cxxx.h>

/* Include project main header file. */

#include "main.h"

/**
 * 24 hour to 12 hour system conversion for the original Litronix display.
 */

#if (APP_WATCH_TYPE_BUILD==APP_PULSAR_WRIST_WATCH_12H_LEGACY_MOD) || \
    (APP_WATCH_TYPE_BUILD==APP_PULSAR_P3_WRIST_WATCH_12H_ODIN_MARK_II_MOD) || \
    (APP_WATCH_TYPE_BUILD==APP_PULSAR_WRIST_WATCH_12H_SIF_LEGACY_MOD) || \
    (APP_WATCH_TYPE_BUILD==APP_PULSAR_P4_WRIST_WATCH_12H_SIF_MARK_II_MOD)

const unsigned char g_24_to_12_hours[] = { /* AM */12, 1, 2, 3, 4, 5, 6, \
                                                    7, 8, 9, 10, 11, \
                                           /* PM */12, 1, 2, 3, 4, 5, 6, \
                                                    7, 8, 9, 10, 11 };

/**
 * 24 hour to AM/PM dot system conversion for the original Litronix display.
 */

const unsigned char g_24_to_AMPM[] = { /* AM */ 1, 1, 1, 1, 1, 1, 1, \
                                                1, 1, 1, 1, 1, \
                                       /* PM */ 2, 2, 2, 2, 2, 2, 2, \
                                                2, 2, 2, 2, 2 };

#endif // Odin and Sif modules

/**
 * 7-segment numerical encoding table
 */

const unsigned char g_numerical_7segment[16] =
{
    //        a b c d e f g
    MAKE_7SEG(1,1,1,1,1,1,0),   // 0
    MAKE_7SEG(0,1,1,0,0,0,0),   // 1
    MAKE_7SEG(1,1,0,1,1,0,1),   // 2
    MAKE_7SEG(1,1,1,1,0,0,1),   // 3
    MAKE_7SEG(0,1,1,0,0,1,1),   // 4
    MAKE_7SEG(1,0,1,1,0,1,1),   // 5
    MAKE_7SEG(1,0,1,1,1,1,1),   // 6
    MAKE_7SEG(1,1,1,0,0,0,0),   // 7
    MAKE_7SEG(1,1,1,1,1,1,1),   // 8
    MAKE_7SEG(1,1,1,1,0,1,1),   // 9
    MAKE_7SEG(0,0,0,0,0,0,1),   // 10 (Minus))
    MAKE_7SEG(0,0,0,0,0,0,1),   // 11
    MAKE_7SEG(0,0,0,0,0,0,1),   // 12
    MAKE_7SEG(0,0,0,0,0,0,1),   // 13
    MAKE_7SEG(0,0,0,0,0,0,1),   // 14
    MAKE_7SEG(0,0,0,0,0,0,1)    // 15
};

/**
 * 7-segment weekday encoding table
 */

const unsigned char g_weekday_7segment[16] =
{
    //        a b c d e f g
    MAKE_7SEG(1,0,1,1,0,1,1),   // S
    MAKE_7SEG(0,1,1,1,1,1,0),   // U
    \
    MAKE_7SEG(1,1,1,0,1,1,0),   // M
    MAKE_7SEG(1,1,1,1,1,1,0),   // O
    \
    MAKE_7SEG(1,0,0,0,1,1,0),   // T
    MAKE_7SEG(0,1,1,1,1,1,0),   // U
    \
    MAKE_7SEG(0,1,1,1,1,1,0),   // W
    MAKE_7SEG(1,0,0,1,1,1,1),   // E
    \
    MAKE_7SEG(1,0,0,0,1,1,0),   // T
    MAKE_7SEG(0,1,1,0,1,1,1),   // H
    \
    MAKE_7SEG(1,0,0,0,1,1,1),   // F
    MAKE_7SEG(1,1,1,0,1,1,1),   // R
    \
    MAKE_7SEG(1,0,1,1,0,1,1),   // S
    MAKE_7SEG(1,1,1,0,1,1,1),   // A
    \
    MAKE_7SEG(0,0,0,0,0,0,0),   // [blank]
    MAKE_7SEG(0,0,0,0,0,0,1),   // -
};

/**
 * BCD to decimal decoding table.
 * 
 * This table returns 0 if a BCD counter is
 * on a not used tetrade.
 */

const unsigned char g_bcd_decimal[160] =
{
    // 0..9 [0x00..0x09 - 0x0A..0x0F]
    0,1,2,3,4,5,6,7,8,9,0,0,0,0,0,0,
    // 10..19 [0x10..0x19 - 0x1A..0x1F]
    10,11,12,13,14,15,16,17,18,19,0,0,0,0,0,0,
    // 20..29 [0x20..0x29 - 0x2A..0x2F]
    20,21,22,23,24,25,26,27,28,29,0,0,0,0,0,0,
    // 30..39 [0x30..0x39 - 0x3A..0x3F]
    30,31,32,33,34,35,36,37,38,39,0,0,0,0,0,0,
    // 40..49 [0x40..0x49 - 0x4A..0x4F]
    40,41,42,43,44,45,46,47,48,49,0,0,0,0,0,0,
    // 50..59 [0x50..0x59 - 0x5A..0x5F]
    50,51,52,53,54,55,56,57,58,59,0,0,0,0,0,0,
    // 60..69 [0x60..0x69 - 0x6A..0x6F]
    60,61,62,63,64,65,66,67,68,69,0,0,0,0,0,0,
    // 70..79 [0x70..0x79 - 0x7A..0x7F]
    70,71,72,73,74,75,76,77,78,79,0,0,0,0,0,0,
    // 80..89 [0x80..0x89 - 0x8A..0x8F]
    80,81,82,83,84,85,86,87,88,89,0,0,0,0,0,0,
    // 90..99 [0x90..0x99 - 0x9A..0x9F]
    90,91,92,93,94,95,96,97,98,99,0,0,0,0,0,0,
};

/**
 * BCD to decimal decoding and testing table.
 * 
 * This table returns 127 if a BCD counter is
 * on a not used tetrade.
 */

const unsigned char g_bcd_decimal_testing[160] =
{
    // 0..9 [0x00..0x09 - 0x0A..0x0F]
    0,1,2,3,4,5,6,7,8,9,127,127,127,127,127,127,
    // 10..19 [0x10..0x19 - 0x1A..0x1F]
    10,11,12,13,14,15,16,17,18,19,127,127,127,127,127,127,
    // 20..29 [0x20..0x29 - 0x2A..0x2F]
    20,21,22,23,24,25,26,27,28,29,127,127,127,127,127,127,
    // 30..39 [0x30..0x39 - 0x3A..0x3F]
    30,31,32,33,34,35,36,37,38,39,127,127,127,127,127,127,
    // 40..49 [0x40..0x49 - 0x4A..0x4F]
    40,41,42,43,44,45,46,47,48,49,127,127,127,127,127,127,
    // 50..59 [0x50..0x59 - 0x5A..0x5F]
    50,51,52,53,54,55,56,57,58,59,127,127,127,127,127,127,
    // 60..69 [0x60..0x69 - 0x6A..0x6F]
    60,61,62,63,64,65,66,67,68,69,127,127,127,127,127,127,
    // 70..79 [0x70..0x79 - 0x7A..0x7F]
    70,71,72,73,74,75,76,77,78,79,127,127,127,127,127,127,
    // 80..89 [0x80..0x89 - 0x8A..0x8F]
    80,81,82,83,84,85,86,87,88,89,127,127,127,127,127,127,
    // 90..99 [0x90..0x99 - 0x9A..0x9F]
    90,91,92,93,94,95,96,97,98,99,127,127,127,127,127,127,
};

/**
 * Decimal to BCD encoding table.
 */

const unsigned char g_decimal_bcd[100] =
{
    0x00,0x01,0x02,0x03,0x04,0x05,0x06,0x07,0x08,0x09,
    0x10,0x11,0x12,0x13,0x14,0x15,0x16,0x17,0x18,0x19,
    0x20,0x21,0x22,0x23,0x24,0x25,0x26,0x27,0x28,0x29,
    0x30,0x31,0x32,0x33,0x34,0x35,0x36,0x37,0x38,0x39,
    0x40,0x41,0x42,0x43,0x44,0x45,0x46,0x47,0x48,0x49,
    0x50,0x51,0x52,0x53,0x54,0x55,0x56,0x57,0x58,0x59,
    0x60,0x61,0x62,0x63,0x64,0x65,0x66,0x67,0x68,0x69,
    0x70,0x71,0x72,0x73,0x74,0x75,0x76,0x77,0x78,0x79,
    0x80,0x81,0x82,0x83,0x84,0x85,0x86,0x87,0x88,0x89,
    0x90,0x91,0x92,0x93,0x94,0x95,0x96,0x97,0x98,0x99
};

/**
 * Modulo 10 table for the 1x digits
 */

const unsigned char g_mod10[100] =
{
    0,1,2,3,4,5,6,7,8,9,    //  0..9
    0,1,2,3,4,5,6,7,8,9,    // 10..19
    0,1,2,3,4,5,6,7,8,9,    // 20..29
    0,1,2,3,4,5,6,7,8,9,    // 30..39
    0,1,2,3,4,5,6,7,8,9,    // 40..49
    0,1,2,3,4,5,6,7,8,9,    // 50..59
    0,1,2,3,4,5,6,7,8,9,    // 60..69
    0,1,2,3,4,5,6,7,8,9,    // 70..79
    0,1,2,3,4,5,6,7,8,9,    // 80..89
    0,1,2,3,4,5,6,7,8,9,    // 90..99
};

/**
 * Div 10 table for the 10x digits
 */

const unsigned char g_div10[100] =
{
    0,0,0,0,0,0,0,0,0,0,    //  0..9
    1,1,1,1,1,1,1,1,1,1,    // 10..19
    2,2,2,2,2,2,2,2,2,2,    // 20..29
    3,3,3,3,3,3,3,3,3,3,    // 30..39
    4,4,4,4,4,4,4,4,4,4,    // 40..49
    5,5,5,5,5,5,5,5,5,5,    // 50..59
    6,6,6,6,6,6,6,6,6,6,    // 60..69
    7,7,7,7,7,7,7,7,7,7,    // 70..79
    8,8,8,8,8,8,8,8,8,8,    // 80..89
    9,9,9,9,9,9,9,9,9,9,    // 90..99
};

/**
 * Table for animating the dot, when
 * the alarm buzzer has been turned on.
 */

#if APP_ALARM_SPECIAL_DOT_ANIMATION==1

const unsigned char g_dot_banner[60] =
{
    4,4,4,4,4,4,4,4,4,4,
    1,1,1,1,1,1,1,1,1,1,
    8,8,8,8,8,8,8,8,8,8,
    2,2,2,2,2,2,2,2,2,2,
    8,8,8,8,8,8,8,8,8,8,
    1,1,1,1,1,1,1,1,1,1,
};

unsigned char g_dot_banner_index = 0;

#endif // #if APP_ALARM_SPECIAL_DOT_ANIMATION==1

/**
 * Global indication for the watch to stay awake. */

unsigned char g_ucStayAwake;

/**
 * Global counters for the timer used to keep the display lit. */

unsigned short g_ucRollOver;
unsigned short g_ucOverallTimeoutLow;
unsigned short g_ucOverallTimeoutHigh;

/**
 * Global button state variables. */

ButtonStateType g_ucPB0TIMEState = PB_STATE_IDLE; // TIME
ButtonStateType g_ucPB1DATEState = PB_STATE_IDLE; // DATE
ButtonStateType g_ucPB2HOURState = PB_STATE_IDLE; // HOUR
ButtonStateType g_ucPB3MINTState = PB_STATE_IDLE; // MIN

/**
 * Global button debounce timer value variables.
 * As all buttons share the same timer for debouncing,
 * we have to keep track of the timer value for each button. */

short g_sPB0Timer = 0;
short g_sPB1Timer = 0;
short g_sPB2Timer = 0;
short g_sPB3Timer = 0;

/**
 Wrist Flick support. */

#if APP_WRIST_FLICK_USAGE==1

ButtonStateType g_ucPB4FLICKState = PB_STATE_IDLE; // WRIST FLICK

short g_sPB4Timer = 0;
short g_FlickTimeSpan = 0;
unsigned char g_WristFlick = 0;

#endif // #if APP_WRIST_FLICK_USAGE==1

/**
 * Global variable indicating which buttons
 * are using the timer 0 for debouncing. */

unsigned char g_ucTimer0Usage = 0;

/**
 * Global variable indicating if timer 2
 * is in use for showing the display. */

unsigned char g_ucTimer2Usage = 0;

/**
 * Multiplexer variable for the digits,
 * reflecting which digit is currently powered. */

unsigned char g_ucMplexDigits = 0;

/**
 * Brightness variable for the digits, reflecting
 * the readout from the AN11 analogue input. */

#if APP_LIGHT_SENSOR_USAGE==1

unsigned char  g_ucDimmingCnt = 0;
unsigned char  g_ucDimmingRef = 0;
unsigned char  g_ucDimming = 0;
unsigned char  g_ucLightSensor = 0;

#endif // #if APP_LIGHT_SENSOR_USAGE==1

/**
 * Current shown values for the left two and right two
 * digits, usually the hours and minutes or month and day. */

unsigned char g_ucLeftVal = 255;
unsigned char g_ucRightVal = 255;

#if APP_BUZZER_ALARM_USAGE

/**
 * Alarm piezo base period value. */

const unsigned char g_ualarm_period = 20 + 64;
const unsigned char g_ualarm_duty_cycle = 10 + 32;

#endif // #if APP_BUZZER_ALARM_USAGE

/**
 * Table to the 7-segment digits, can be set to numerical or character table. */

const unsigned char *g_pDigits;

/**
 * Variable, reflecting the state of the Dot-LED's on the display,
 * in between month and day or hour and minute. */

#if APP_WATCH_TYPE_BUILD!=APP_PROTOTYPE_BREAD_BOARD

unsigned char g_ucDots = 0;

#endif

/**
 * If using the Pulsar Autoset button mode, there
 * are two button press counters for the TIME and DATE
 * buttons, that are reset, when the display is turned off.
 */

#if APP_WATCH_ANY_PULSAR_MODEL == APP_WATCH_PULSAR_AUTO_SET

unsigned char g_ucTimePressCnt = 0;
unsigned char g_ucDatePressCnt = 0;

#endif // #if APP_WATCH_ANY_PULSAR_MODEL == APP_WATCH_PULSAR_AUTO_SET

/**
 * In order not to change the display mode while multiplexing
 * store a copy of the display state, when the multiplexing
 * cycle had started. */

DisplayStateType g_uDispState;
DisplayStateType g_uDispStateBackup;

/**
 * Alarm counter, cancelled by expiring or pressing a button. */

#if APP_BUZZER_ALARM_USAGE==1
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
void main(void)
{
    unsigned char udivider;

    /* Initialize and configure. */

    Init_Inputs_Outputs_Ports();
    Configure_Inputs_Outputs();

    Configure_Timer_0();
    Configure_Timer_1();
    Configure_Timer_2();
    Configure_Timer_3();
    Configure_Timer_4();

    Configure_Real_Time_Clock();
    
    Init_Button_States();

    /* If the controller has been waken up from deep sleep, we have to unlock
     * the general purpose inputs and outputs first. */

    if (WDTCONbits.DS == 1)
    {
        /* Clear deep sleep status bits and release GPIOS from
         * deep sleep lock. */

        WDTCONbits.DS = 0;

        // DEEP SLEEP CONTROL LOW BYTE REGISTER
        DSCONLbits.RELEASE = 0; //  Clear to unfreeze the I/O's.

        /* The two general purpose registers of the MCU are non-volatile and
         * survive the deep sleep mode. They are named DSGPR0 and DSGPR1. */

        // DSGPR0
        // DSGPR1
    }
    else
    {
        /* Turn the 'stay awake' timer off again. */

  #if APP_WATCH_ANY_PULSAR_MODEL!=APP_WATCH_GENERIC_BUTTON

        // Magnet set or Auto-set Pulsar wrist watch.
        
        TMR2 = 0;               // Zero the timer.
        T2CONbits.TMR2ON = 1;   // Turn timer 2 on.
        g_ucTimer2Usage = 1;    // Indicate using the timer.

        /* Set the display state to time reading. */

        g_uDispState = DISP_STATE_TIME;
        
  #if APP_BUZZER_ALARM_USAGE==1

        /* Turn the alarm buzzer on. */

        Turn_Buzzer_On(448/*duration*/);

  #endif // #if APP_BUZZER_ALARM_USAGE==1

  #else // #if APP_WATCH_ANY_PULSAR_MODEL!=APP_WATCH_GENERIC_BUTTON

        /* Set the display state to blank. */

        g_uDispState = DISP_STATE_BLANK;

  #endif // #else #if APP_WATCH_ANY_PULSAR_MODEL!=APP_WATCH_GENERIC_BUTTON
    }
    
    /* Enable global interrupts.
     * INTERRUPT CONTROL REGISTER */

    // Global Interrupt Enable bit
    INTCONbits.GIE = 1;      // Enables all unmasked interrupts
    // Peripheral Interrupt Enable bit
    INTCONbits.PEIE = 1;     // Enables all unmasked peripheral interrupts

    /* INTERRUPT CONTROL REGISTER 2 */

    // External Interrupt 0 Edge Select bit
    INTCON2bits.INTEDG0 = 1; // Interrupt on rising edge
    // External Interrupt 1 Edge Select bit
    INTCON2bits.INTEDG1 = 1; // Interrupt on rising edge
    // External Interrupt 2 Edge Select bit
    INTCON2bits.INTEDG2 = 1; // Interrupt on rising edge
    // External Interrupt 3 Edge Select bit
    INTCON2bits.INTEDG3 = 1; // Interrupt on rising edge

    /* PORTB Pull-up Disable bit
     * 
     * RBPU: PORTB Pull-up Enable bit
     * 1 - All PORTB pull-ups are disabled
     * 0 - PORTB pull-ups are enabled by individual port tri-state values
     */
    
    INTCON2bits.RBPU = 1;    // All PORTB pull-ups are disabled.

    /* Init Multiplexing for digits. */

    g_ucMplexDigits = 0;
    
  #if APP_LIGHT_SENSOR_USAGE==1

    g_ucDimmingCnt = 0;
    g_ucDimming = 0;
    g_ucDimmingRef = 0;

  #endif // #if APP_LIGHT_SENSOR_USAGE==1
    
    /* Init local variables. */

    g_ucStayAwake = 0;
    g_ucRollOver = 1;

    udivider = 0;

    /* Cancel the overall timeout to prevent the battery from draining
     * if a button is pressed and left unattended for too long. */

    Clear_Overall_Timeout();

    /* Main watch logic loop. */
    
    while (1)
    {
        /* Check alarm. */

      #if APP_BUZZER_ALARM_USAGE==1

        if (PIR3bits.RTCCIF) // PERIPHERAL INTERRUPT REQUEST (FLAG) REGISTER 3
        {
            PIR3bits.RTCCIF = 0;     // Clear RTCC interrupt.

            /* Reset the alarm repeat. */

            ALRMRPT = 255;

            /* Turn the alarm buzzer on. */

            Turn_Buzzer_On(6000/*duration*/);
            
            /* Initialize dot animation. */
            
          #if APP_ALARM_SPECIAL_DOT_ANIMATION==1
            
            g_dot_banner_index = 0;
            
          #endif
        }

      #endif // #if APP_BUZZER_ALARM_USAGE==1

        /* Debounce the buttons. */

        g_ucStayAwake = DebounceButtons();

        /* Handle 'stay awake' timer for keeping the display
         * on for a short while. */

        if (g_ucTimer2Usage)
        {
            if (TMR2 >= 0xA0)
            {
                TMR2 = 0;

              #if APP_BUZZER_ALARM_USAGE==1

                /* Check if the alarm buzzer is still active. */

                unsigned short *palarm = &g_ucAlarm;

                if (*palarm)
                {
                    (*palarm)--;

                    /* Turn the alarm buzzer off, if required. */

                    const unsigned short ualarm = *palarm;

                    if (!ualarm)
                    {
                        Turn_Buzzer_Off();
                    }
                    else
                    {
                        Turn_Buzzer_Fancy((ualarm >> 6) & 0x07);
                        
                        /* Do the dot animation. */
            
                    #if APP_ALARM_SPECIAL_DOT_ANIMATION==1

                        unsigned char udot = g_dot_banner_index;
                        
                        udot++;
                        
                        if (udot >= (sizeof(g_dot_banner) << 2))
                        {
                            udot = 0;
                        }
                        
                        g_dot_banner_index = udot;

                    #endif
                    }

                    /* If there is still the alarm buzzer activated,
                     * restart the rollover counter with a short value. */

                    g_ucRollOver = 100;
                }

              #endif // #if APP_BUZZER_ALARM_USAGE==1

                /* Counter for keeping the display on. */

            #if APP_WATCH_ANY_PULSAR_MODEL==APP_WATCH_PULSAR_AUTO_SET

                const DisplayStateType istate = g_uDispState;
                const unsigned short ulimit = \

                            /* Using AutoSet, keep the display lit for long. */

                            (istate >= DISP_STATE_AUTOSET_TIME) ? 1250 : \

                            /* Grant more time on a wrist flick event. */
                                
                            g_WristFlick ? 525 : 375;

                if (++g_ucRollOver >= ulimit) // Rounds per second.
                {
            #else

                if (++g_ucRollOver >= 375) // Rounds per second.
                {
                    const DisplayStateType istate = g_uDispState;

            #endif
                    /* Check if all button states are idle. */

                    if ( /* No button pressed. */

                        (!g_ucPB0TIMEState) && \
                        (!g_ucPB1DATEState) &&
                            
                      #if APP_WATCH_ANY_PULSAR_MODEL!=APP_WATCH_PULSAR_AUTO_SET

                        (!g_ucPB2HOURState) && \
                        (!g_ucPB3MINTState) &&

                      #endif

                        /* Display not in 'watch stalled' mode. */
                            
                        (istate != DISP_STATE_SECONDS_STALLED))
                    {
                        /* If using the Pulsar Autoset button mode. */

                    #if APP_WATCH_ANY_PULSAR_MODEL==APP_WATCH_PULSAR_AUTO_SET

                        if ((istate == DISP_STATE_AUTOSET_TIME) && \
                            (g_ucTimePressCnt == HINT_AUTOSET_MINUTES_SET))
                        {
                            /* Unlock write access to the RTC and disable the clock. */

                            Unlock_RTCC();

                            /* Enabling writing to the RTC. */

                            RTCCFGbits.RTCWREN = 1;

                            /* Stop the RTC */

                            RTCCFGbits.RTCEN = 0;

                            /* Set the RTC register to read/write. */

                            RTCCFG &= ~3;
                            //while(RTCCFGbits.RTCSYNC);

                            /* Zero the seconds. */

                            RTCVALL = 0;

                            /* Indicate the the watch had been stopped. */

                            g_uDispState = DISP_STATE_SECONDS_STALLED;
                        }
                        else

                    #endif // #if APP_WATCH_ANY_PULSAR_MODEL == APP_WATCH_PULSAR_AUTO_SET

                        {
                            /* If no button is still pressed, turn the 'awake'
                             * timer off. */

                            T2CONbits.TMR2ON = 0;

                            /* Indicate that we do not need to stay awake
                             * anymore. */

                            g_ucRollOver = 0;
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

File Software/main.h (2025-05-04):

/**
 *  Copyright (c) 2020-25 Roy Schneider
 *
 *  main.h
 *
 *  Decllaration for the Pulsar P3 internal watch logic.
 *
 *  Project:            Pulsar Replacement module 'Odin & Loki' and 'Sif & Hel'.
 *
 *  Programmer:         Roy Schneider
 *  Last Change:        04.05.2025
 *
 *  Language:           C
 *  Toolchain:          GCC/GNU-Make
 *
 * Software License Agreement
 *
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
 * As a special exception, if other files instantiate templates or
 * use macros or inline functions from this file, or you compile
 * this file and link it with other works to produce a work based
 * on this file, this file does not by itself cause the resulting
 * work to be covered by the GNU General Public License. However
 * the source code for this file must still be made available in
 * accordance with section (3) of the GNU General Public License.
 *
 * This exception does not invalidate any other reasons why a work
 * based on this file might be covered by the GNU General Public
 * License.
 */
 
/**
 * Define all the possible watch types, supported by this WatchApp.
 * 
 * Maximum output current by PORTB, PORTC and RA6 I/O pin is 25 mA.
 */

// P3 - Original Litronix P2/P3 display.
#define APP_PULSAR_P3_WRIST_WATCH_12H_ODIN_MARK_II_MOD     0 // Pulsar P3 Odin Mark II module with driver transistors.
// P3 - First prototype replacement module.
#define APP_PULSAR_WRIST_WATCH_12H_LEGACY_MOD              1 // First legacy prototype P3 module.
// P3 - USSR made ALS314/AL304G replacement displays.
#define APP_PULSAR_P3_WRIST_WATCH_24H_LOKI_MOD             2 // Pulsar P3 Loki module.
// P4 - USSR made ALS314/AL304G replacement displays.
#define APP_PULSAR_P4_WRIST_WATCH_24H_HEL_MOD              3 // Pulsar P4 Hel module.
// P4 - First prototype replacement module.
#define APP_PULSAR_WRIST_WATCH_12H_SIF_LEGACY_MOD          4 // First legacy prototype P4 module.
// P4 - Original Litronix P4 display.
#define APP_PULSAR_P4_WRIST_WATCH_12H_SIF_MARK_II_MOD      5 // Pulsar P4 Sif Mark II module with driver transistors.
// Litronix/Siemens bubble display bread board.
#define APP_PROTOTYPE_BREAD_BOARD                          6 // Just my breadboard.

/**
 * ========================================================================
 * Choose the watch module type, that shall be build, right here.
 * ========================================================================
 */
 
#define APP_WATCH_TYPE_BUILD    APP_PULSAR_P3_WRIST_WATCH_12H_ODIN_MARK_II_MOD

/* Note:
 * 
 * If building for the Loki or Hel module, do not forget to select below, if
 * featuring a common cathode ALS314 or common anode AL304G replacement
 * display. I do prefer the AL304G displays, because they are easier to read
 * in daylight. */

/* ======================================================================== */

/**
 * Common cathode/anode value definitions. */

#define APP_WATCH_COMMON_CATHODE    0   // Value for common cathode.
#define APP_WATCH_COMMON_ANODE      1   // Value for common anode.
#define APP_WATCH_COMMON_OPTO       2   // Value for common opto-couplers.

/**
 * Define the possible types of buttons and their operation mode. */

#define APP_WATCH_GENERIC_BUTTON    0   // Table Watch and Breadboard
#define APP_WATCH_PULSAR_MAGNET_SET 1   // P3 magnet set
#define APP_WATCH_PULSAR_AUTO_SET   2   // P4 auto set

/**
 * Define to turn on display dimming via a LDR and the alarm feature.
 * 
 * Important note: The following features are mutual exlcude:
 * 
 * - APP_LIGHT_SENSOR_USAGE
 * - APP_BUZZER_ALARM_USAGE
 * - APP_WRIST_FLICK_USAGE
 * 
 * To put it into a nutshell. You can't combine those together. */

#if (APP_WATCH_TYPE_BUILD == APP_PULSAR_P3_WRIST_WATCH_12H_ODIN_MARK_II_MOD)
  // P3 - Odin (original display, common cathode, using driver transistors))
  #define APP_WATCH_COMMON_PIN_USING                 APP_WATCH_COMMON_CATHODE
  #define APP_WATCH_ANY_PULSAR_MODEL                 APP_WATCH_PULSAR_MAGNET_SET
  #define APP_LIGHT_SENSOR_USAGE                     1
  #define APP_LIGHT_SENSOR_USAGE_DEBUG_SHOW_VALUE    1
  #define APP_BUZZER_ALARM_USAGE                     0
  #define APP_DATE_SPECIAL_DOT_USAGE                 0
  #define APP_ALARM_SPECIAL_DOT_ANIMATION            0
  #define APP_WRIST_FLICK_USAGE                      0
  #define APP_COMMON_DRIVER_POSITIVE                 1 // For NMOS driving.
  #define APP_ONE_TIME_BUTTON_OPERATION              0
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

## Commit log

2020-11-12 Added layout and source files.
    [watch_rev3.brd, watch_rev3.sch]
2020-11-12 Added PCB preview files.
2020-11-14 Added loki board using l104g replacement displays.
    [loki_mod.brd, loki_mod.sch]
2020-11-15 Update the watch application to support the Loki module.
    [loki_mod.brd, loki_mod.sch]
2020-11-15 Updated Loki board file.
    [loki_mod.brd]
2020-11-15 Fixed cathodes handling for USSR made replacement display.
    [main.c]
2020-11-19 Added resitor for date dot, if using the USSR replacement made display.
    [loki_mod.brd, loki_mod.sch]
2020-11-22 Added toggling between common anode/cathode for Loki boards.
2020-11-28 Increased TRACE and VIA width were possible.
    [loki_mod.brd, loki_mod.sch]
2020-11-30 Added frame for alarm buzzer feature.
    [main.c, main.h]
2020-12-01 Added alarm decimal point.
    [loki_mod.brd, loki_mod.sch]
2020-12-01 Added buzzer PWM output feature.
    [main.c, main.h]
2020-12-02 Worked further on the buzzer alarm feature.
    [main.c]
2020-12-07 If no light sensor is used, turn all IO to digital.
2020-12-07 Improved layout of Loki board using USSR made replacement display.
    [loki_mod.brd, loki_mod.sch]
2020-12-10 Fixed changing display state while multiplexing.
    [main.c]
2020-12-13 Added PDF's of schematics and board files.
2020-12-19 Optimized layout for manual soldering.
    [loki_mod.brd, loki_mod.sch, watch_rev3.sch]
2020-12-20 Added the buzzer solder pad for the 'Loki' board.
    [loki_mod.brd, loki_mod.sch]
2020-12-22 Connected unused dots for digit 1 and 3.
    [loki_mod.brd, loki_mod.sch]
2020-12-22 Small layout improvements.
    [loki_mod.brd]
2020-12-30 After feedback from the manufacturer of the PCB the outer PCB shape has been improved.
    [loki_mod.brd]
2021-01-08 Fixed some DRC issues.
    [loki_mod.brd, loki_mod.sch]
2021-01-10 Added resitor for piezo.
    [loki_mod.brd, loki_mod.sch]
2021-01-10 Fixed alarm dot and 24h default setup of the hours.
    [main.c, main.h]
2021-01-24 Updated resitor values and fine tuned some traces.
    [loki_mod.brd, loki_mod.sch, watch_rev3.brd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]
2021-01-24 Added close-up of a hand soldered loki module.
2021-02-13 Added RTC calibration feature.
2021-02-18 Optimized layout and Litronix display footprint.
    [loki_mod.brd, watch_rev3.brd, watch_rev3.sch]
2021-02-26 Moved GND-VIA to make it unlikely to short it, when soldering the resistor next to it.
    [loki_mod.brd]
2021-02-27 Fixed resistor value.
    [watch_rev3.brd, watch_rev3.sch]
2021-03-14 Updated pdf files.
    [watch_rev3.brd, watch_rev3.sch]
2021-03-15 Adjusted trace width.
    [loki_mod.brd]
2021-05-05 Reworked layout for odin and loki boards.
    [loki_mod.brd, loki_mod.sch, odin_mod.brd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]
2021-05-10 Started to add support for the P4 (403) replacement modules.
    [main.c, main.h]
2021-05-13 Fine tuned light sensor impact on display brightness.
2021-05-13 Firmware update, traces optimized.
    [loki_mod.brd, odin_mod.brd]
2021-05-15 Lowered impact of light sensor.
2021-08-25 Optimized Odin and Loki layout.
    [loki_mod.brd, loki_mod.sch, odin_mod.brd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]
2021-08-26 Updated instructions about adjusting the drift calibration.
2021-09-05 Optimized the traces.
    [loki_mod.brd]
2021-11-27 Reviewed boards and code.
    [loki_mod.brd, loki_mod.sch, odin_mod.brd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]
2022-01-09 Power consumption for ODIN module is now down to 7uA.
2022-01-22 Updated PCB previews.
2022-08-16 Reviewed Odin module.
    [odin_mod.brd]
2022-10-23 Updated schematics comments.
    [loki_mod.brd, loki_mod.sch]
2022-10-23 Added P4 Executive Module featuring the original Litronix made display.
    [sif_mod.brd, sif_mod.sch]
2022-11-12 If wrist flick and button is indicated more or less together, the button will restart the lit-up-counter.
2022-12-17 Pushed VCAP to the bootm layer.
    [sif_mod.brd]
2023-01-08 Optimized C code after having reviewed the assembly listing.
2023-02-15 Optimized SiF layout.
    [sif_mod.brd]
2023-08-25 Improved one trace to make it less likely to short it when soldering the board.
    [sif_mod.brd]
2023-11-11 Released ODIN MkII featuring n-mos transistors for the common cathodes.
    [odin_mod.brd, odin_mod.sch]
2023-11-11 Updated image files.
    [odin_mod.brd, odin_mod.sch]
2023-11-11 Added loki pcb preview.
2023-11-11 Added odin mk II pcb preview.
2023-11-19 Reworked PCB edges for the Sif module.
    [sif_mod.brd]
2023-11-21 Made Sif board edges wider.
    [sif_mod.brd]
2023-12-05 Lowered values of the segment resistors for the Sif board.
    [sif_mod.brd, sif_mod.sch]
2023-12-06 Added odin mk ii wiring.
2023-12-06 Updated wiring drawing.
2023-12-23 Upgraded Sif module to use nmos transistors for the common cathodes.
    [sif_mod.brd, sif_mod.sch]
2023-12-23 Added required software changes for the upgraded SiF module.
    [odin_mod.brd, odin_mod.sch]
2023-12-23 Updated footprint of 10 uF ceramic cap to 0602.
    [sif_mod.brd, sif_mod.sch]
2024-01-03 Moved Frist Flick pads.
    [sif_mod.brd]
2024-01-04 Added ODIN parts list.
    [odin_mod.brd]
2024-01-05 Lowered resistor values a bit.
    [loki_mod.brd, loki_mod.sch]
2024-01-06 Eliminated one display pin pass-through.
    [loki_mod.brd]
2024-01-20 Tested ONE-BUTTON mode.
2024-05-12 Improved segment resistor values.
    [sif_mod.brd, sif_mod.sch]
2024-05-12 Lowered segment resistors and optimized traces.
    [odin_mod.brd, odin_mod.sch]
2024-10-25 Optimized ODIN II layout by means of having more space to solder the two transistors below the display.
    [odin_mod.brd]
2024-10-27 Increased trace with of some connections.
    [odin_mod.brd]
2025-08-16 Added overall DATE/TIME button timeout.

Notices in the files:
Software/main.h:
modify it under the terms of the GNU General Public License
